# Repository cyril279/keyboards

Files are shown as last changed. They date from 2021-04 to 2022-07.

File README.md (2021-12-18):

# One42 | low-profile 42-key Wireless
choc-v2 & v1 switches, MX-spaced, integrated/onboard nrf52840 controller  
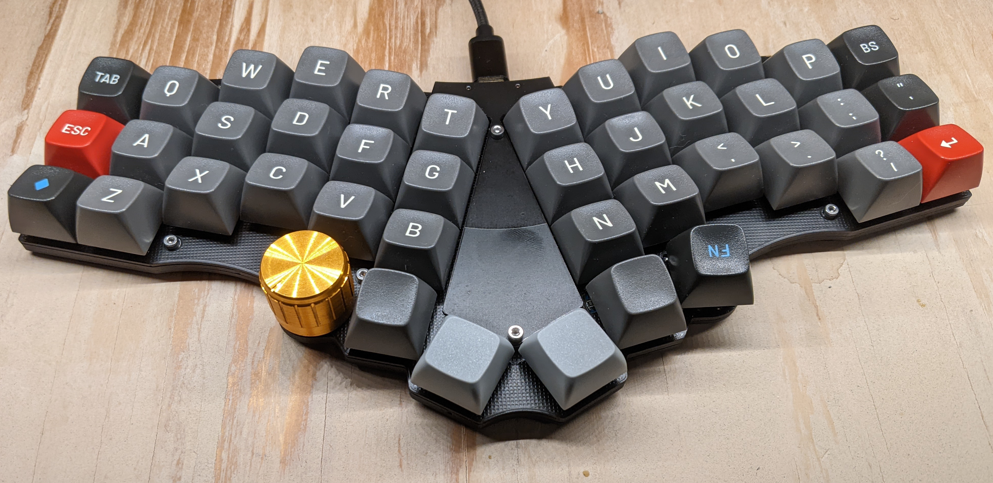
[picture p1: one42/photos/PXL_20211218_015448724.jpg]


# rev41l2 / 41-1353 | low-profile Reviung41 variant
choc-v2 & v1 switches, MX-spaced  
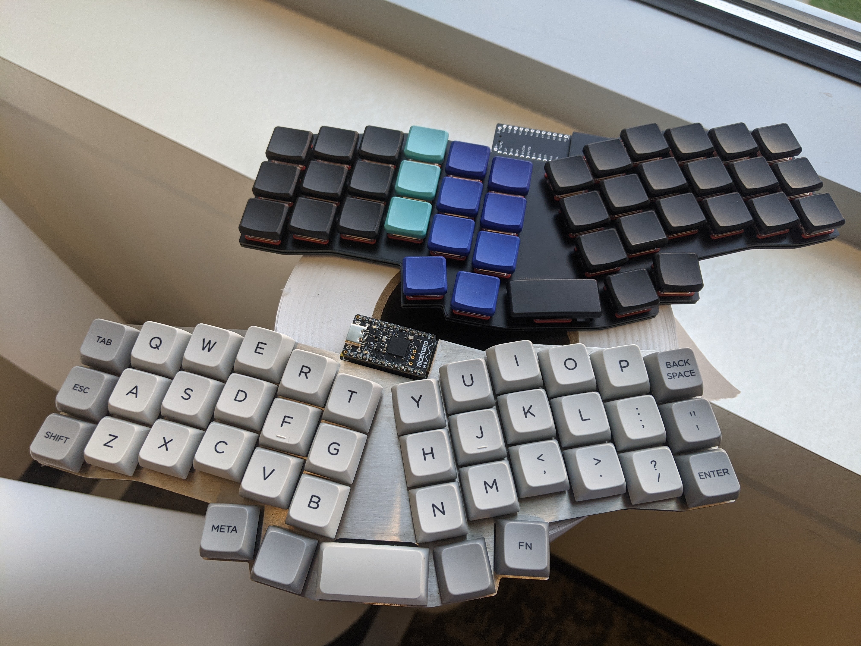
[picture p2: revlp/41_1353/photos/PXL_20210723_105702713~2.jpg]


# rev41lp / 41-1350 | low-profile Reviung41 variant
choc-v1 switches, choc-spaced, hotswap, single-color backlit  
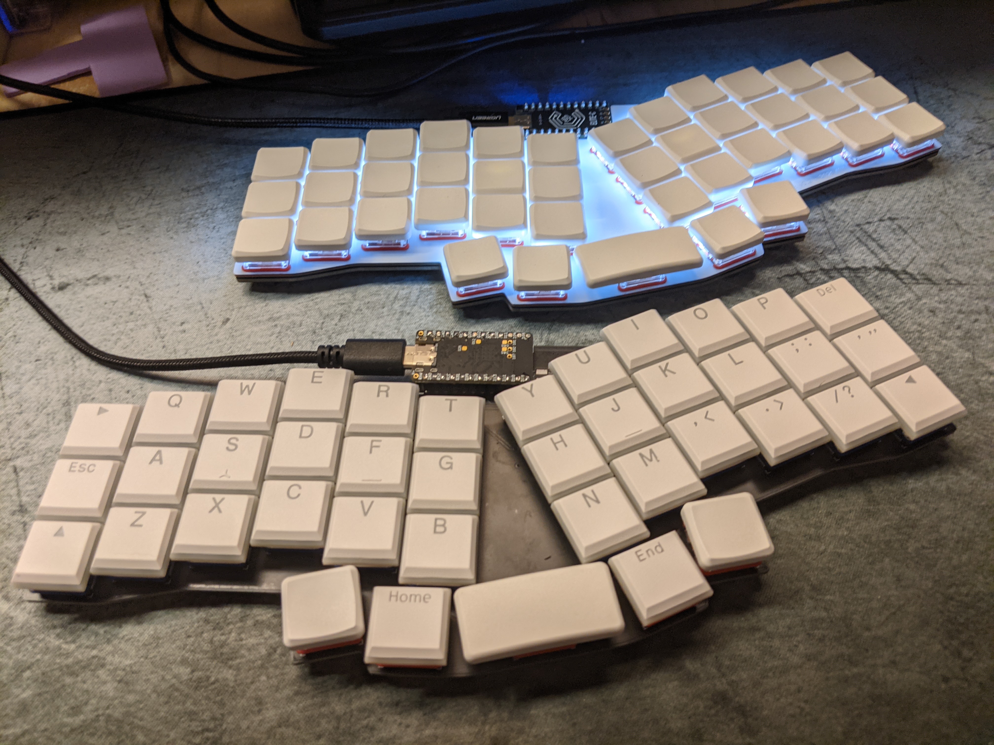
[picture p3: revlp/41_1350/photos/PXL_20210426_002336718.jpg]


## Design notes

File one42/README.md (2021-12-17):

# One42 | 42-key Wireless
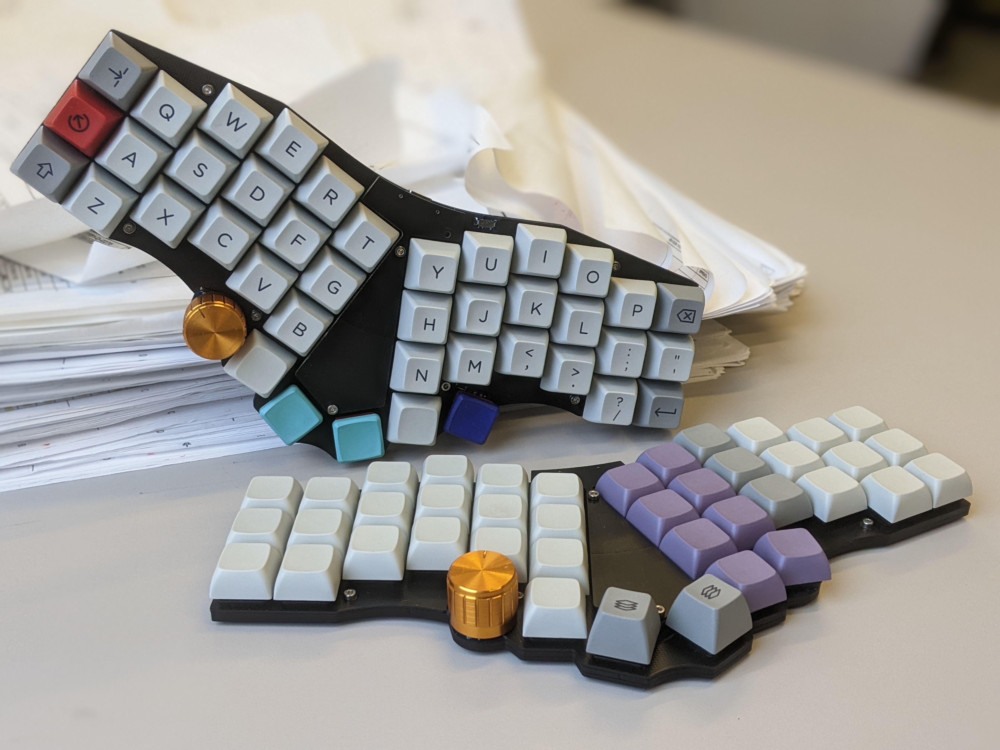
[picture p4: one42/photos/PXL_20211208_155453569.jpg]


- v2 (& v1) choc switches (soldered)
- Integrated/onboard wireless controller (holyiot 18010; hello ZMK!)
- 18.8mm sq.spacing (most keycap dimensions are actually 18.0-18.3mm)
- 30 degree angled halves
- Rotary encoders (2x optional) at outer-thumb positions **
- 100% Hand-solderable
- Minimally cased by Integrated switchplate, skid-plate, & component-cover

## Firmware
[zmk-config](https://github.com/cyril279/zmk-config-one42) << fork, adjust the keymap, and let github build your firmware.  
There are links to the bootloader (if needed), as well as flashing instructions at the link-above.  
For more info on ZMK itself, [* start here *](https://zmk.dev/docs)  

## Encoder fitment
The placement of these encoders allows the use of 21mm diameter knobs.  
  At this diameter, some of the knobs are able to fit down over the body of the encoder for a lower-profiled encoder.  
  Shown below is a 12mm tall encoder adorned with a 21mm diameter knob.  
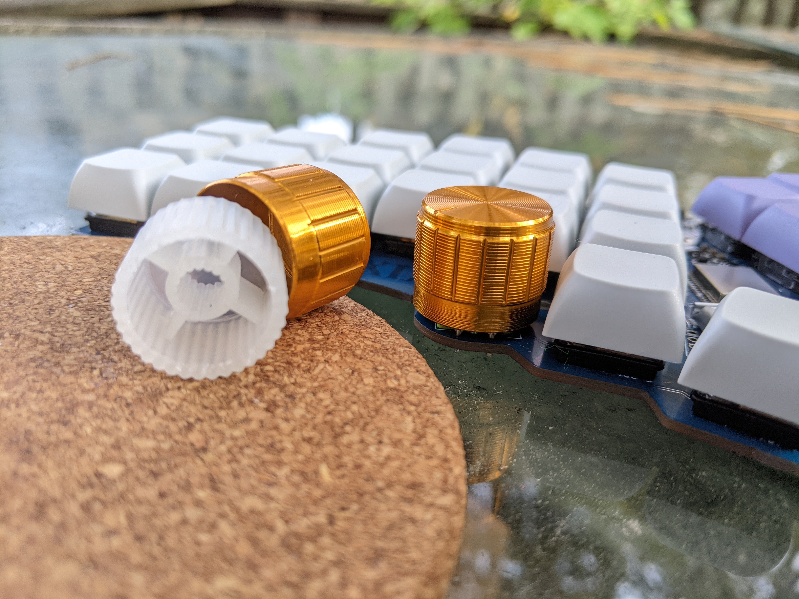
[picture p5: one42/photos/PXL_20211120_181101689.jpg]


## Encasement
A switch-plate, skid-plate, and component cover were designed to make this build nicer to handle and to look at.  
- The switchplate is a 1mm fr4 plate which helps to align the switches, as well as increase curb-appeal. By design, this gets soldered to the pcb via the plated mount-holes.  
- The skidplate is a 1.6mm fr4 plate designed to be fastened to the bottom of the pcb, creating a surface that is much more friendly to handle and have in a bag or backpack, while minimally increasing the height of the overall build.  
- The component-cover is another fr4 plate that covers the topside components.  

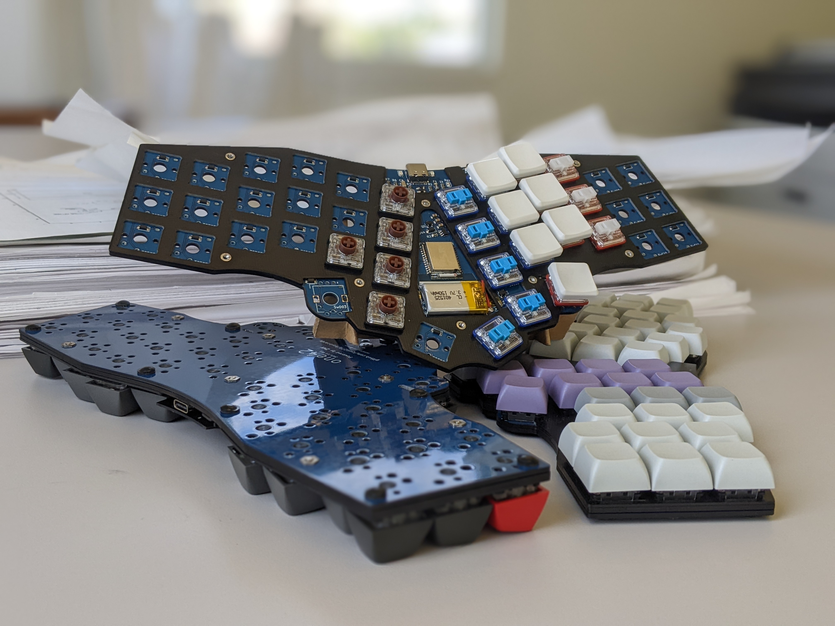
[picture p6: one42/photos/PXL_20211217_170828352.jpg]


## Lessons-learned v0.1 / plans & thoughts for v0.2
1) The pg-1353 switches do not self-align well without a switch-plate.  
  I had hoped (assumed) that the third-leg of the 1353's would do a sufficient job of positioning the switches.  
  My previous designs all involved switch-plates (for aesthetic reasons) so I was unaware that this would be an issue.    
  Switch-plate will be... less optional.  
2) The oval holes for the encoder remove the alignment features for the pg-1350 (choc-v1) switches.  
  The switchplate helps, but does not completely remedy this issue.  
3) Skidplate:  
    a) I will experiment with plating the mount-holes, so that the threaded-inserts can be soldered.  
    b) Leave the copper fill out of the antenna region. This does not seem to affect the current boards, but it was an oversight that it is not removed directly below the antenna.  
4) Component cover: This needs a better finish, but copper filling the whole thing is not an option, because it risks wrecking the wireless signal.  

## Thank You.
- [gtips reviung41](https://github.com/gtips/reviung) was the initial inspiration  
- [dezli’s ahokore](https://github.com/dezlidezlidezli/ahokore) was the template for the zmk-config & electrical-schematic  
- The [low-profile keyboard discord](https://discord.gg/eEK5yUh) is wonderfully encouraging and supportive  
- All things open-source!

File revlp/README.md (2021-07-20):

# Rev-lp
Inspired by the [reviung series](https://github.com/gtips/reviung), designed specifically for Kailh choc switches v1 & v2 (pg1350 & pg1353).  

39_1350 | 39-key Reviung, 18x17mm spacing, v1 switches; hotswap, single-color backlit

[41_1350](./41_1350) | 41-key Reviung, 18x17mm spacing, v1 switches; hotswap, single-color backlit
[](./41_1350)

[41_1353](./41_1353) | 41-key Reviung, 19mm square spacing, v2 (& v1) switches; soldered switches, no lighting
[](./41_1353)

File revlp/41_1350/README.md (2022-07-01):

Cover

# Rev-lp
Inspired by the [reviung series](https://github.com/gtips/reviung), designed specifically for Kailh pg1350 (choc) switches.  

[Build Pics](build.md)  

### Firmware
[QMK](https://github.com/qmk/qmk_firmware/tree/master/keyboards/b_sides/rev41lp)  
[ZMK](https://github.com/cyril279/zmk-config-rev41_1350/tree/main/config)

### Geometric differences from the reviung series:  
- 18mm x 17mm choc key-spacing
- Thumb-row spacing changed to accommodate choc keycap availability 
26 degree splay in between right and left key-groups (gtips’ reviung is 20 degrees)

### Functional differences:  
- Pinouts are different (lack of forethought, this may change)
- Removed underglow (because low-profile)
- Added Per-key (single color), under-switch backlighting
- Addition of battery pads and power switch for use with a bluetooth controller

Mechanical & electronic layouts were performed in fusion360 & kicad (respectively).

### V0.2:
- working as of 2021/04/22 

# Bill of Materials:  

## Required:  
- 1N4148 Smd diodes, SOD-123 / SOD-80 / miniMelf package (39/41)  
- Pg1350 kailh sockets (39/41)  
- Pg1350 switches (39/41)  
- 2u choc stabilizer
- Pro micro (or equivalent)  

## Optional:
- Reset switch ([Alps SKSN series](https://tech.alpsalpine.com/prod/e/html/tact/surfacemount/sksn/sksn_list.html))

### Bluetooth controller:  
- Battery  
- Batt power switch ([Alps SSSS811101](https://tech.alpsalpine.com/prod/e/html/switch/slide/ssss8/ssss811101.html))

### Backlighting:  
- 3528 led's (39/41)  
- Resistors (see backlighting notes), 1206 or melf 0204 package, 1/8 watt (39/41)  
- 4.7k resistor, 1206 or melf 0204 package, 1/8 watt (1)  
- N-channel AO3416 MOSFET, SOT-23 package (1)  

Backlighting notes:  
1. The resistor value needed is determined by specific characteristics of the led's chosen, as well as the voltage supplied by the controller. The specific characteristics can differ for various types and colors of led's.  
2. Use an [led calculator](https://ledcalculator.net/) to determine the resistor value (all ⅛ watt):  
Recommendation: Use minimum resistor needed to protect led, then limit brightness via `BACKLIGHT_LIMIT_VAL` to limit the max to a reasonable value (PWM manged, so more power efficient)  
3. VCC voltage is different for nice!nano from pro-micro; pin 24 is raw on pro-micro, but not on elite-c.  
**V+ choice matters!**  

I am a mechanical cad-person, but I am not a circuit or code whiz, which slowed the effort, and attenuated my ambition.  The success of this project is a direct result of those who took the time to document and publicize their journeys (& kicad projects/libraries), and a supportive low-profile discord community.

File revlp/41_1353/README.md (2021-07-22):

# Reviung41-lp2
Inspired by the [reviung series](https://github.com/gtips/reviung), designed specifically for Kailh pg1353 (choc-v2) switches.  
(Compatible with choc-v1 switches for those that prefer an mx-spaced reviung41)

Cover

This is as low as MX gets.  
Cover

**Firmware:** The pinout is the same as the original reviung41, so the existing Reviung41 firmware ([QMK](https://github.com/qmk/qmk_firmware/tree/master/keyboards/reviung41) or [ZMK](https://zmk.dev/docs/hardware#keyboard-shields)) works for this device.  

**[[ Build Guide ]](build.md)** (work-in-progress)  

**[[ Stabilizer Installation ]](build.md#stabilizer-installation)**  
I have not yet provided guidance on how to mod the bar from its stock-state to work with choc-v2 switches.  
The offset/bent portion of the bar needs to be nearly flat.  

# Bill of Materials:  

## Required:  
- 1N4148 Smd diodes, SOD-123 / SOD-80 / miniMelf package (41)  
- Pg1350 switches (41)  
- 2u costar stabilizer
- Pro micro (or equivalent)  

### Bluetooth controller:  
- Battery  
- Batt power switch ([Alps SSSS811101](https://tech.alpsalpine.com/prod/e/html/switch/slide/ssss8/ssss811101.html))

Initial version notes:

Design:
- Diodes can be mounted under switches, or onto back of PCB
- Switchplate can be soldered to PCB or clipped to switches (depending on desired keycap clearance)
- Use of the switchplate prevents opening of switches while soldered

Notes for future iterations:
- pcb: arrows for stabilizer orientation?
- switch cutout dimension (differs per application):
  - 13.95mm square for v2's that are expected to clip into the plate.
  - 13.8mm square for integrated-plate usage, as well as choc v1 usage. <- More likely scenario
- 2u cutout: Make 1mm wider
- PCB-connection points should be through-hole. (eliminate possibility of lifting the pad | stronger connection of pcb-to-switchplate)
- Thickness (differs per application)
  - 1.6mm when v2-switch clip-in (this option has poor cap compatibility, but looks stellar when applicable)
  - 1.2mm when solder-to-PCB (provides maximum cap compatibility. 1.6mm works, but is awfully close)
- Experiment with 18.5mm spacing.

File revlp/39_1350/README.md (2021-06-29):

!! stay tuned for pics and guide !!

# Bill of Materials:  

## Required:  
- 1N4148 Smd diodes, 1206 package (39)  
- Pg1350 kailh sockets (39)  
- Pg1350 switches (39)  
- pro micro (or equivalent)  

## Optional:
- reset switch ([Alps SKSN series](https://tech.alpsalpine.com/prod/e/html/tact/surfacemount/sksn/sksn_list.html))

### Bluetooth controller:  
- battery  
- batt power switch ([Alps SSSS811101](https://tech.alpsalpine.com/prod/e/html/switch/slide/ssss8/ssss811101.html))

### Backlighting:  
- 3528 led's (39)  
- Resistors (see backlighting notes), 1206 package, 1/8 watt (39)  
- 4.7k resistor, 1206 package, 1/8 watt (1)  
- N-channel AO3416 MOSFET, SOT-23 package (1)  

Backlighting notes:  
1. The resistor value needed is determined by specific characteristics of the led's chosen, as well as the voltage supplied by the controller. The specific characteristics can differ for various types and colors of led's.  
2. Use an [led calculator](https://ledcalculator.net/) to determine the resistor value (all ⅛ watt):  
Recommendation: Use minimum resistor needed to protect led, then limit brightness via `BACKLIGHT_LIMIT_VAL` to limit the max to a reasonable value (PWM manged, so more power efficient)  
3. VCC voltage is different for nice!nano from pro-micro; pin 24 is raw on pro-micro, but not on elite-c. **V+ choice matters!**

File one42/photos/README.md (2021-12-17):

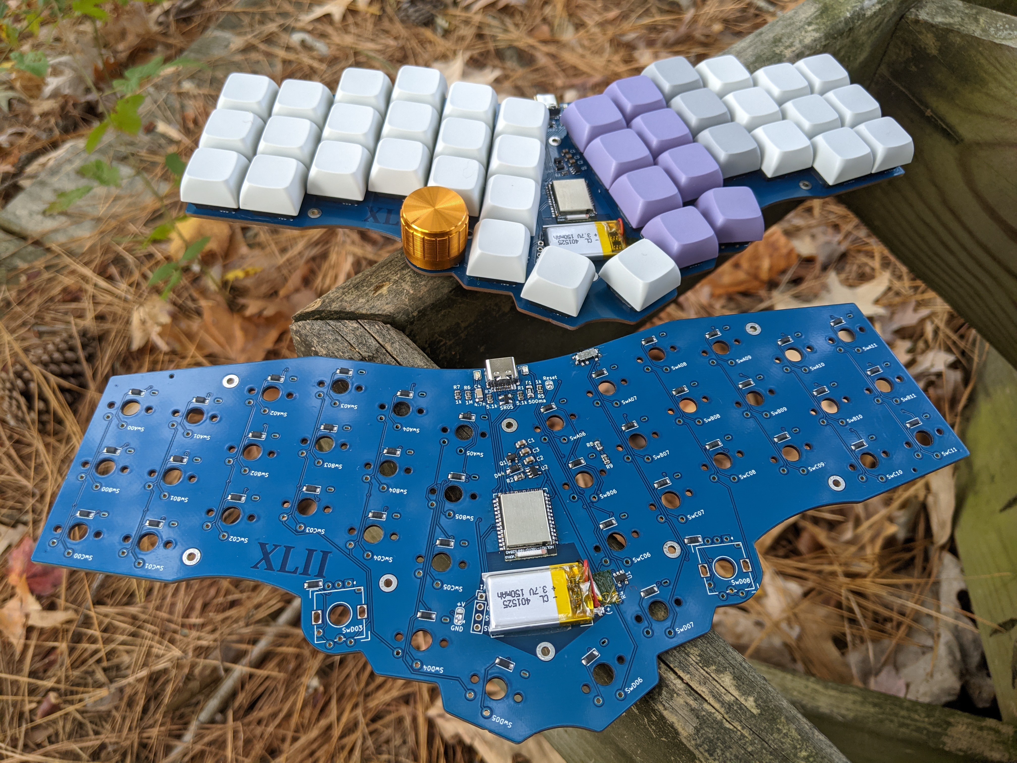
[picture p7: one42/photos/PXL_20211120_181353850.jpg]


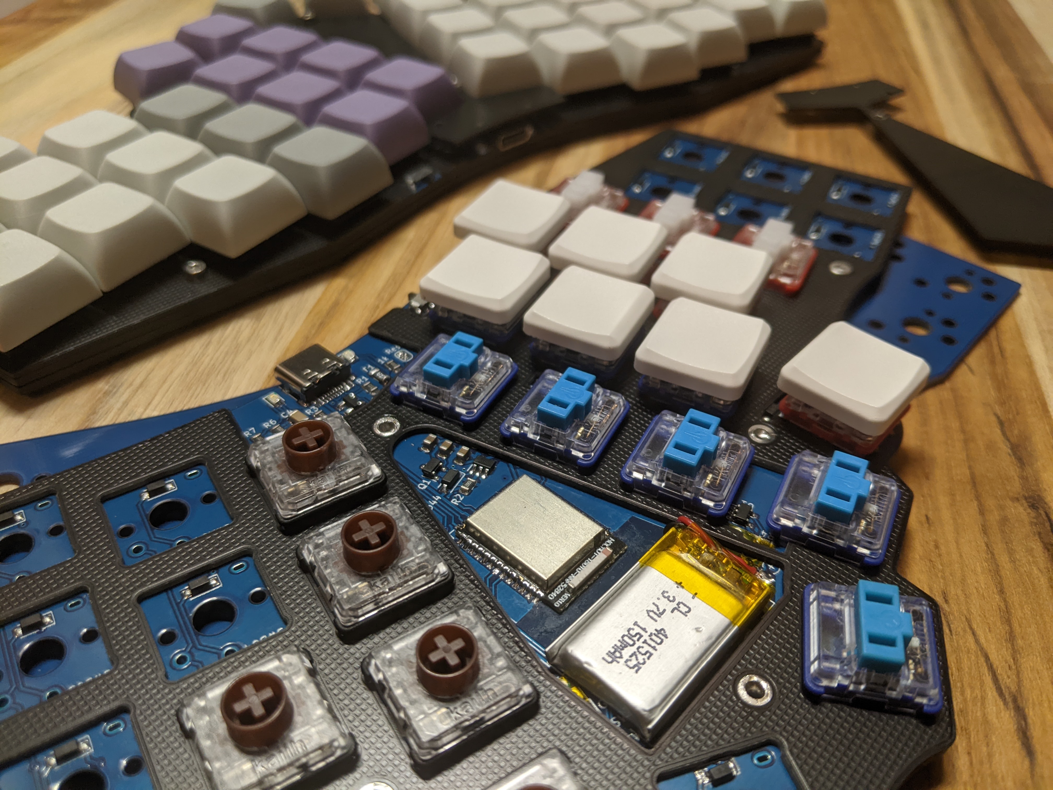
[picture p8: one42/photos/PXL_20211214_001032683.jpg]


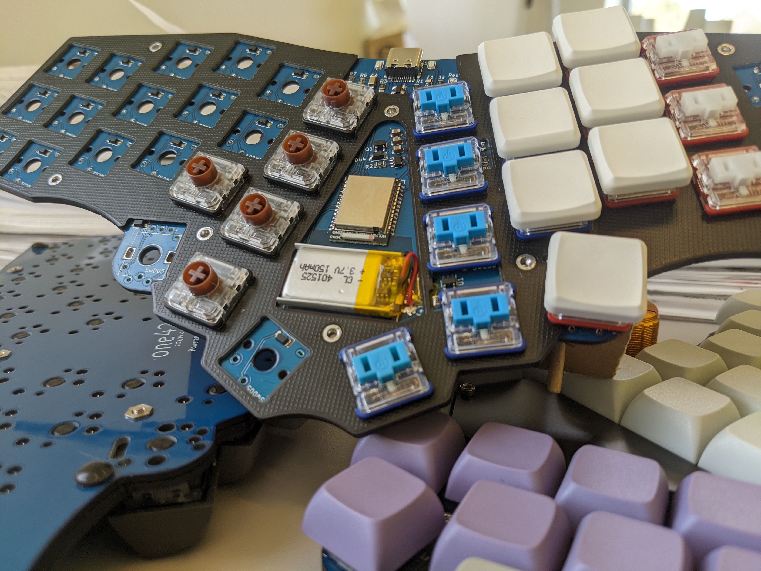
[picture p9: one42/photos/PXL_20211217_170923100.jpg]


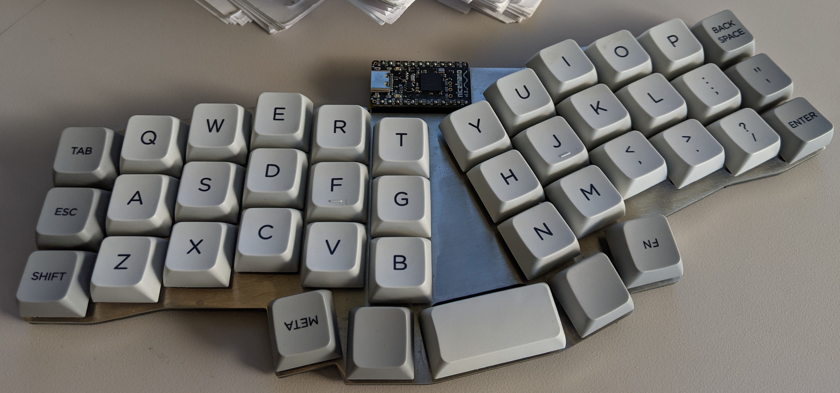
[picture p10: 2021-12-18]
revlp/41_1353/photos/PXL_20210806_121746867_b.jpg

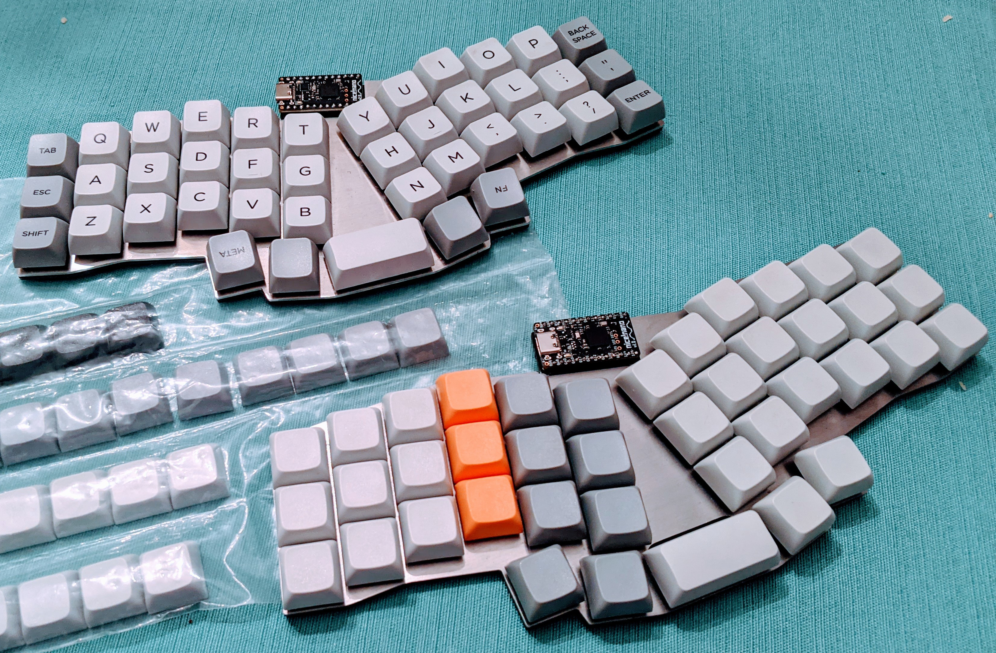
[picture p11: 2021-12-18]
revlp/41_1353/photos/PXL_20210904_000339602~2.jpg

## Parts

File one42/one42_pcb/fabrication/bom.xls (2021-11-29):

Comment | Designator | Footprint | JLCPCB Part #
10k | R4,R2 | 0805 | C17414
4.7uF | C1 | 0805 | C1779
AO3401A | Q1 | SOT-23-3L | C15127
5.1k | R3,R1 | 0805 | C27834
D_Small | D1,D2,D3,D4,D5,D6,D7,D8,D9,D10,D11,D12,D13,D14,D15,D16,D17,D18,D19,D20,D21,D22,D23,D24,D25,D26,D27,D28,D29,D30,D31,D32,D33,D34,D35,D36,D37,D38,D39,D40,D41,D42 | SOD-123 | C81598
2M | R9 | 0805 | C26112
1k | R7,R5 | 0805 | C17513
1uF | C2,C3 | 0805 | C28323
TP4054 | U1 | SOT-23-5 | C32574
1M | R6 | 0805 | C17514

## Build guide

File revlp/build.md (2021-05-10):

build00

Core functionality only requires diodes, hotswap sockets, and a pro-micro compatible controller.  
build02  

Controller must be soldered on face-down.  
I highly recommend socketing the controller.  
build03  

The black strips are .063", adhesive-backed neoprene foam. They provide support while inserting switches, and slightly damp the acoustics of the assembly.  
build04  
The switchplate is not necessary, but I like the added functionality of the 2u stabilizer, as well as the added support provided to the switches.  
build05  

Backlighting:  
Solder mosfet, pull-down resistor (4.7kohm), and led resistors as shown.  
You must choose whether you want for the +V power source to come from the VCC pin, or the RAW (24th) pin of the controller.  
build06  
Align triangle corner of the led with the white corner of the pad.  
build07  

Bluetooth controller (such as nice!nano):  
There are pads on the PCB so that the battery power can be run across an external power switch (also built into the pcb)  
build08

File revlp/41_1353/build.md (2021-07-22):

## Core functionality
1) Flash & test controller
2) Solder diodes (can be soldered to the top or bottom side of pcb)
3) Solder controller to pcb (& test pcb)  


## Bluetooth controller
Solder the battery and power-switch to the pcb (& test again)  




## Integrated Switchplate Installation:
  

Rubber-band the PCB & switchplate together (alignment is not important here)  

  

Insert a few switches (to align the switchplate), but do not raise the switchplate to clip to the switches.  
Leave the switchplate in direct contact with the pcb, the way the rubber-bands are holding them.  
  

Flip the assembly to rest on the switches.  
  

Apply solder to the joint-holes in-between the switches (this joins the pcb & plate together)  
There are twelve.  
  

Complete.
  

## Stabilizer installation
Install guides into PCB with the bar-clip toward the back  


Install inserts into keycap with the offset toward the front  
& install the bar into the inserts with the bend away from the cap-edge  


...with a switch installed...  


Flip the keycap/insert/bar assembly onto the switch  


Align the keycap & inserts to the switch & guides.  
Press the keycap down onto the switch  


Use your bar-insertion tool to press the bar into the clips  



Done.

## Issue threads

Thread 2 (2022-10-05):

Curious Inconsistency On 41_1353 Switch Plate

alexmadeathing, 2022-10-05:
Hi, I was about to order some plates using your files but I noticed a strange inconsistency in the files. One of the 12 solder points that joins the two pcbs together is a drill. Is there a reason I'm not understanding?

My assumption is that all 12 solder points should be the same, either solder pads or drills.

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

cyril279, 2022-10-05:
This was intentional. It has nothing to do with the functionality of the keyboard; instead, I recall that it was related to tricking the JLCPCB system into accepting/interpreting the gerber files correctly.  Otherwise you are correct: ideally those points should all be the same, whether drills or solder pads.

alexmadeathing, 2022-10-05:
Ahh fair enough. And I guess it's better to have just one reasonably hidden via than changing them all to vias and them being more visible.

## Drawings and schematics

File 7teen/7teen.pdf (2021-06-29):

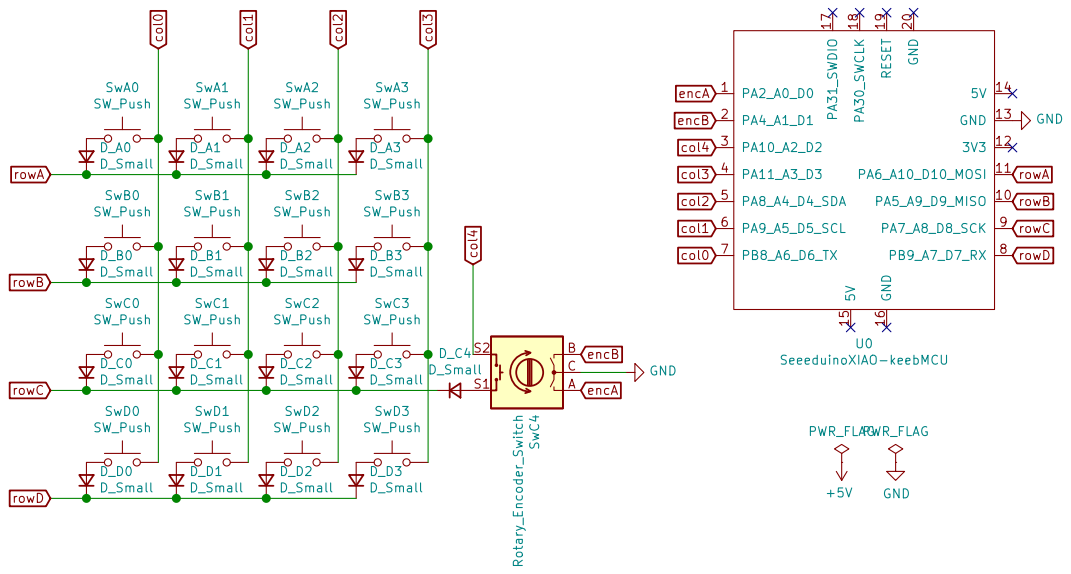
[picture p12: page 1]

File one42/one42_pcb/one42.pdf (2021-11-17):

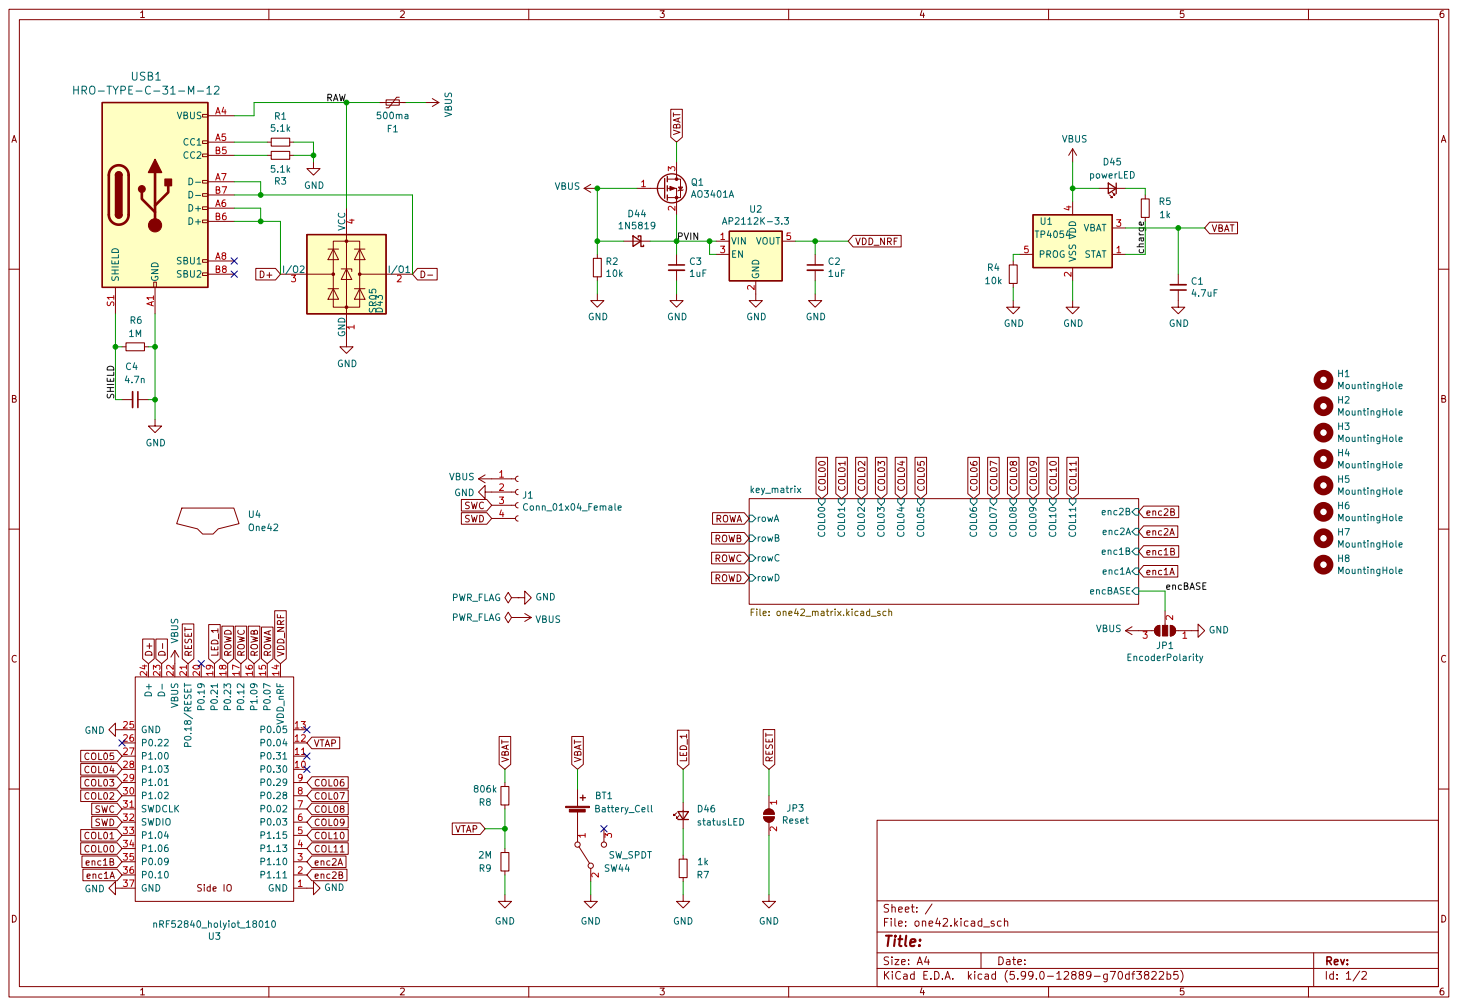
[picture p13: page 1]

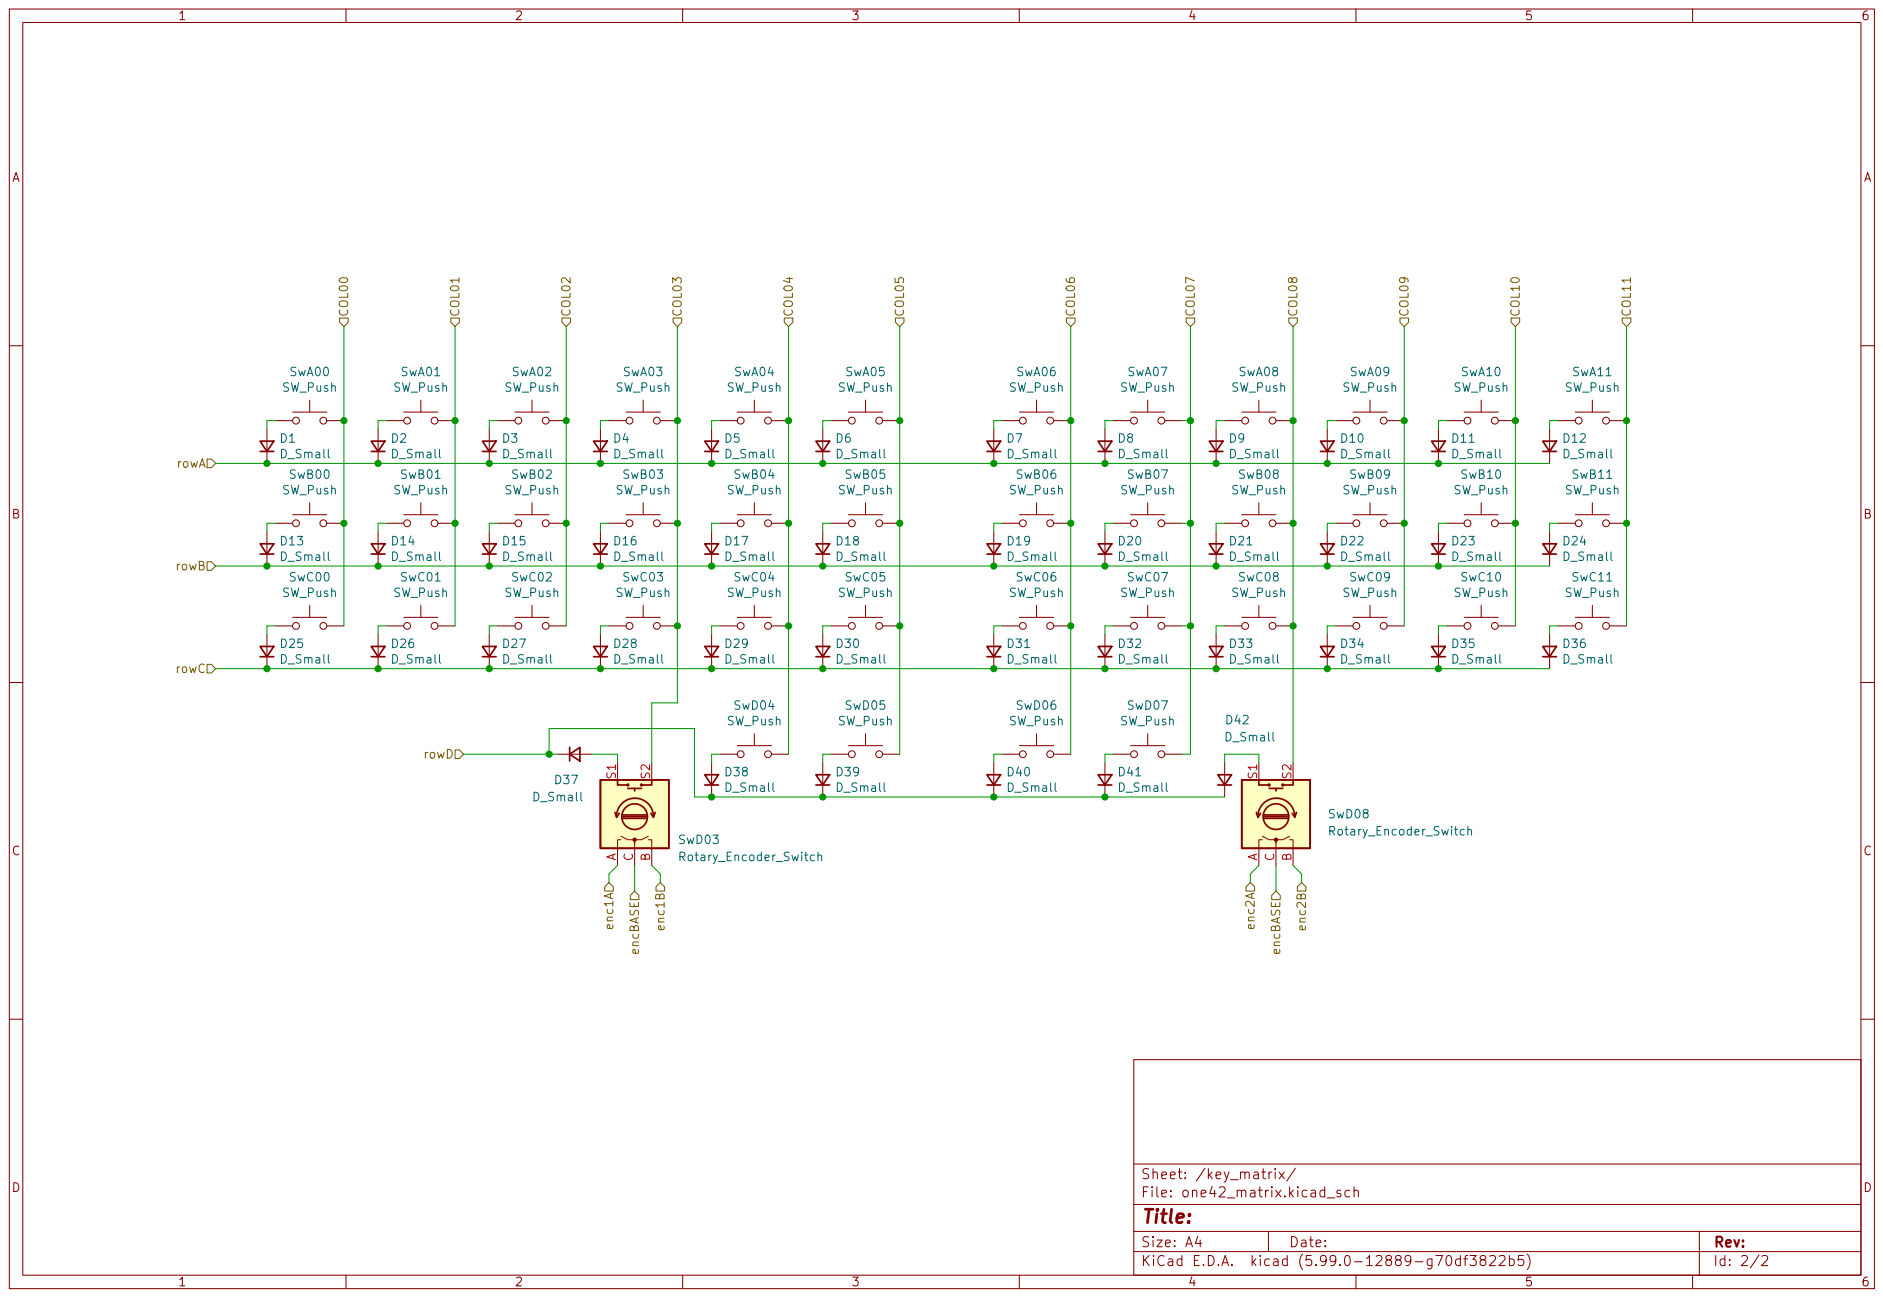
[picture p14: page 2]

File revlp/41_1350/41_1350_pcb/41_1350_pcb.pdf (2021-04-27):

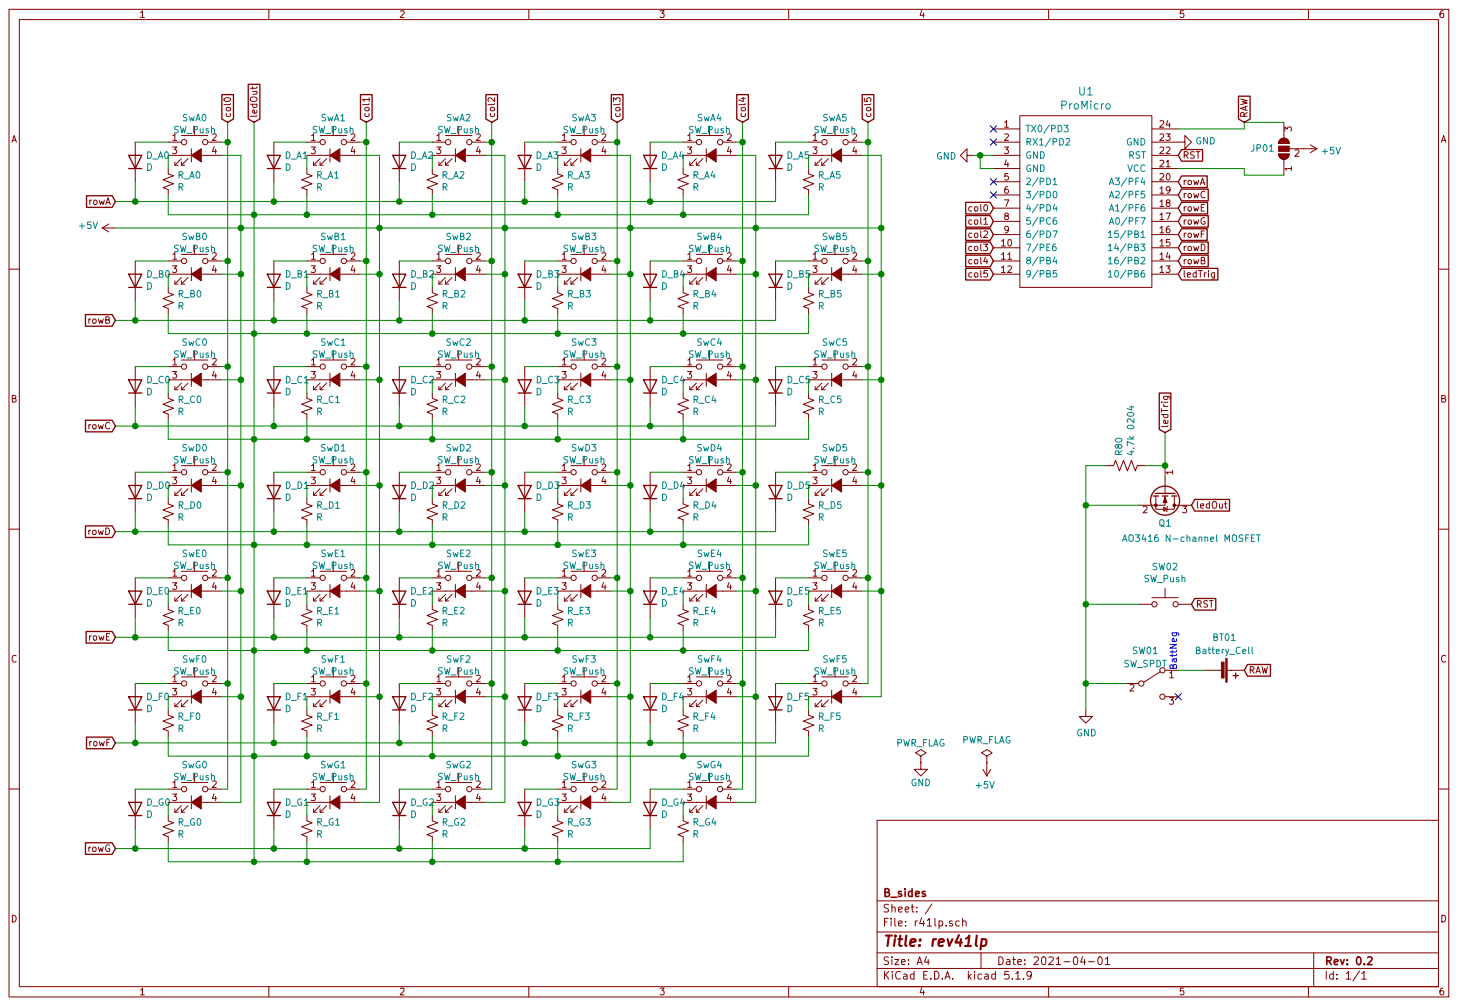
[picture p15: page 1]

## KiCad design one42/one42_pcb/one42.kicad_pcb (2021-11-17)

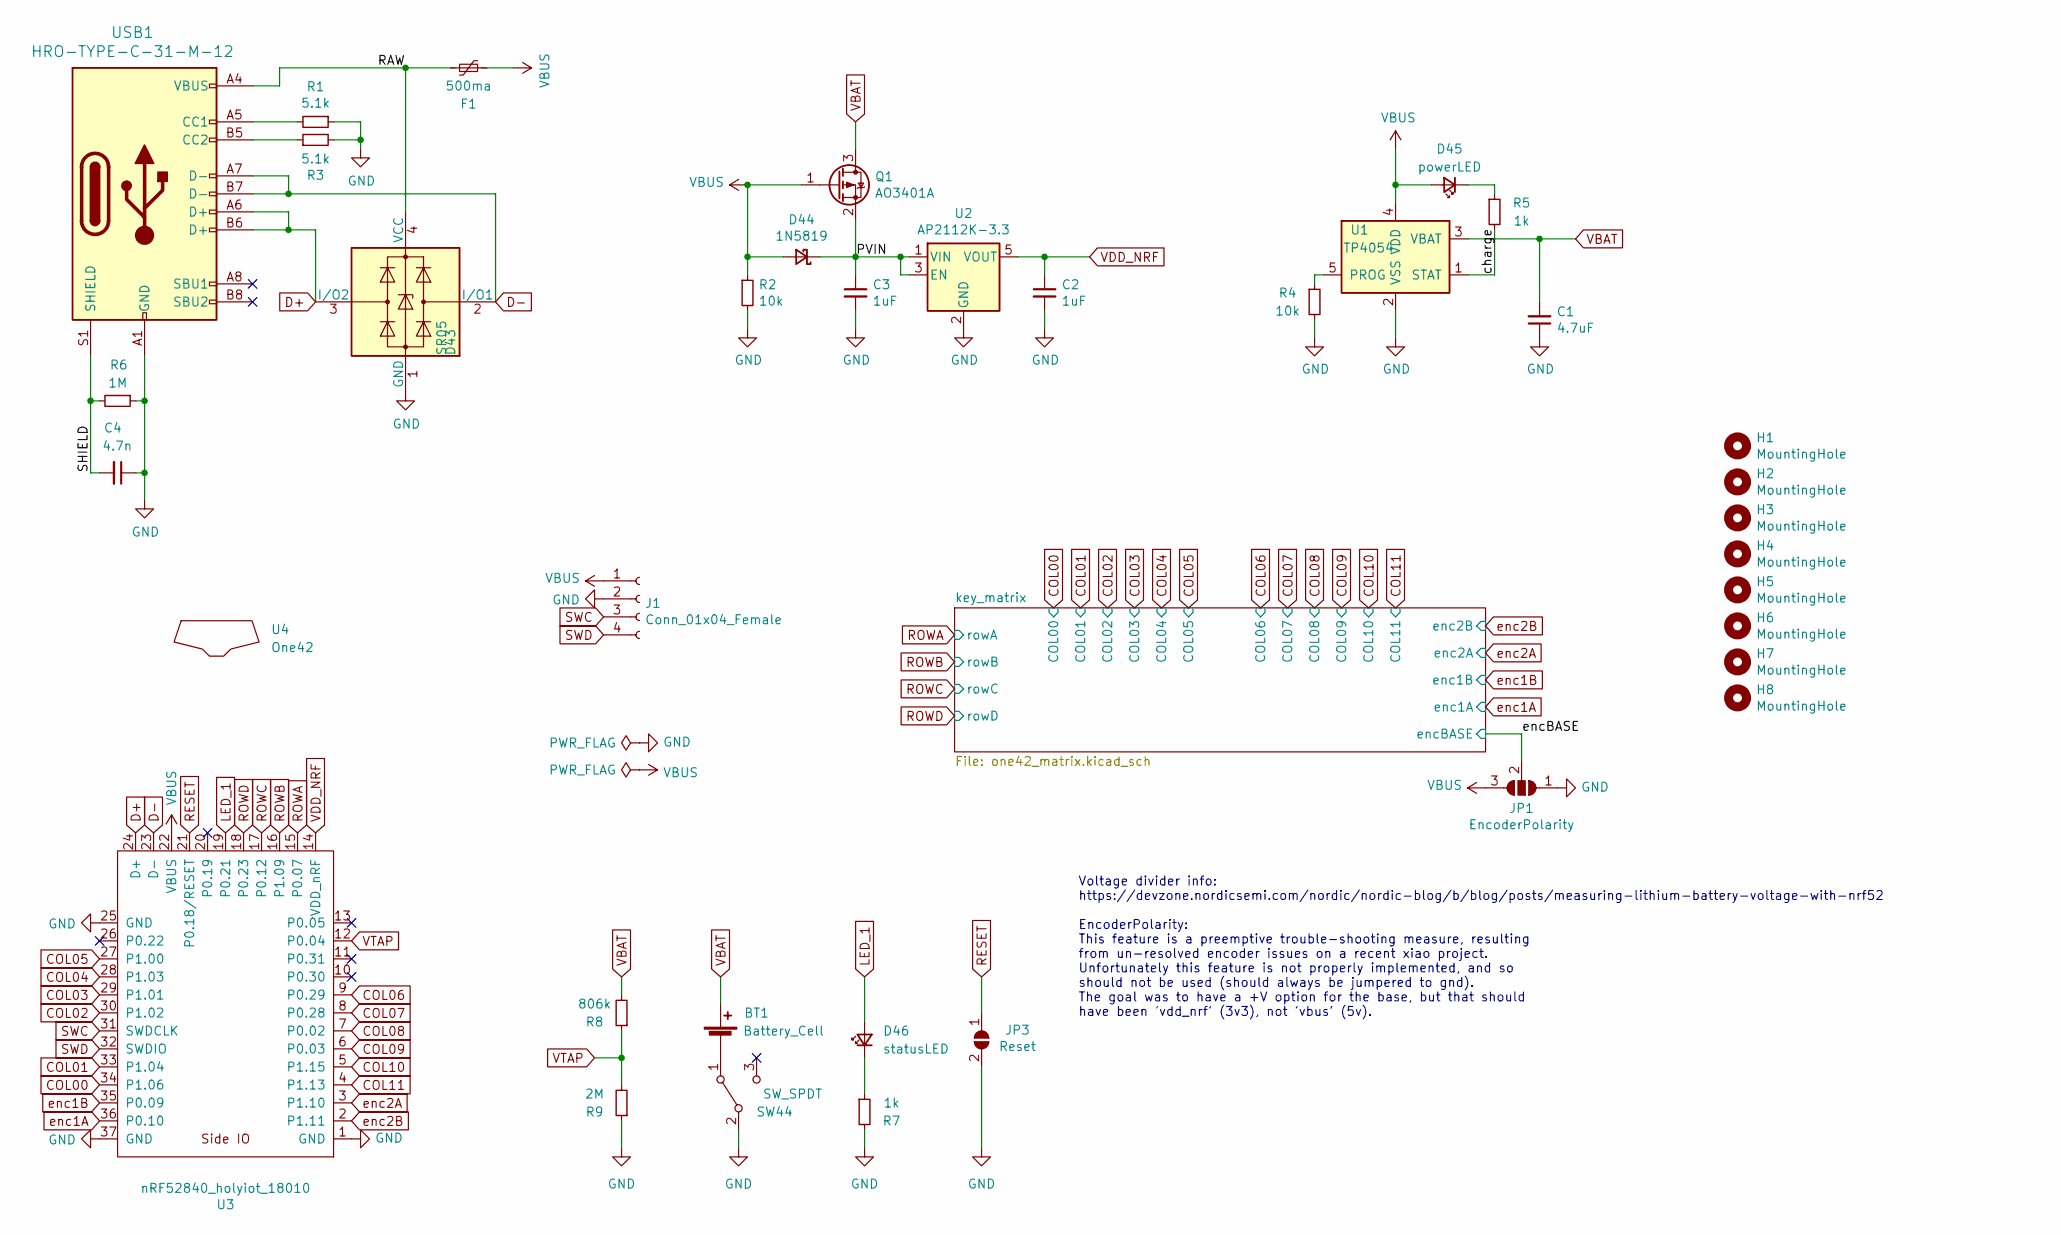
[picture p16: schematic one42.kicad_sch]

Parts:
BT1: Battery_Cell; cell_pads
C1: 4.7uF; C_0805_2012Metric; JLC 0805
C2, C3: 1uF; C_0805_2012Metric; JLC 0805
C4: 4.7n; C_1206_3216Metric
D43: SR05; SOT-143
D44: 1N5819; D_SOD-123
D45: powerLED; D_0805_2012Metric
D46: statusLED; D_0805_2012Metric
F1: 500ma; Fuse_1206_3216Metric
H1, H2, H3, H4, H5, H6, H7, H8: MountingHole; MountingHole_2.2mm_M2_Pad
J1: Conn_01x04_Female; PinHeader_1x04_P2.54mm_Vertical
JP1: EncoderPolarity; SolderJumper-3_P1.3mm_Open_RoundedPad1.0x1.5mm
JP3: Reset; SolderJumper-2_P1.3mm_Open_RoundedPad1.0x1.5mm
Q1: AO3401A; SOT-23; JLC SOT-23-3L
R1, R3: 5.1k; R_0805_2012Metric; JLC 0805
R2, R4: 10k; R_0805_2012Metric; JLC 0805
R5, R7: 1k; R_0805_2012Metric; JLC 0805
R6: 1M; R_0805_2012Metric; JLC 0805
R8: 806k; R_0805_2012Metric
R9: 2M; R_0805_2012Metric; JLC 0805
SW44: SW_SPDT; switch_SSSS811101
U1: TP4054; SOT-23-5; JLC SOT-23-5
U2: AP2112K-3.3; SOT-23-5
U3: nRF52840_holyiot_18010; nRF52840_holyiot_18010_HS_simple
U4: One42; one42
USB1: HRO-TYPE-C-31-M-12; USB_C_Receptacle_HRO_TYPE-C-31-M-12_handsolder

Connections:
/PVIN: C3.1, D44.1 (K), Q1.2 (S), U2.1 (VIN), U2.3 (EN)
/RAW: D43.4 (VCC), F1.2, USB1.A4 (VBUS), USB1.A9 (VBUS), USB1.B4 (VBUS), USB1.B9 (VBUS)
/SHIELD: C4.2, R6.2, USB1.S1 (SHIELD)
/charge: R5.2, U1.1 (STAT)
/encBASE: JP1.2 (C); also elsewhere on the board
COL00: U3.34 (P1.06); also elsewhere on the board
COL01: U3.33 (P1.04); also elsewhere on the board
COL02: U3.30 (P1.02); also elsewhere on the board
COL03: U3.29 (P1.01); also elsewhere on the board
COL04: U3.28 (P1.03); also elsewhere on the board
COL05: U3.27 (P1.00); also elsewhere on the board
COL08: U3.7 (P0.02); also elsewhere on the board
COL09: U3.6 (P0.03); also elsewhere on the board
COL10: U3.5 (P1.15); also elsewhere on the board
COL11: U3.4 (P1.13); also elsewhere on the board
D+: D43.3 (I/O2), U3.24 (D+), USB1.A6 (D+), USB1.B6 (D+)
D-: D43.2 (I/O1), U3.23 (D-), USB1.A7 (D-), USB1.B7 (D-)
GND: C1.1, C2.2, C3.2, C4.1, D43.1 (GND), J1.2, JP1.1 (A), JP3.2 (B), R1.1, R2.2, R3.2, R4.2, R6.1, R7.2, R9.1, SW44.2 (B), U1.2 (VSS), U2.2 (GND), U3.1 (GND), U3.25 (GND), U3.37 (GND), USB1.A1 (GND), USB1.A12 (GND), USB1.B1 (GND), USB1.B12 (GND)
LED_1: D46.2 (A), U3.19 (P0.21)
unnamed: BT1.2 (-), SW44.1 (A)
unnamed: D45.1 (K), R5.1
unnamed: D46.1 (K), R7.1
unnamed: R1.2, USB1.A5 (CC1)
unnamed: R3.1, USB1.B5 (CC2)
unnamed: R4.1, U1.5 (PROG)
RESET: JP3.1 (A), U3.21 (P0.18/RESET)
ROWA: U3.15 (P0.07); also elsewhere on the board
ROWB: U3.16 (P1.09); also elsewhere on the board
ROWC: U3.17 (P0.12); also elsewhere on the board
ROWD: U3.18 (P0.23); also elsewhere on the board
SWC: J1.3, U3.31 (SWDCLK)
SWD: J1.4, U3.32 (SWDIO)
VBAT: BT1.1 (+), C1.2, Q1.3 (D), R8.2, U1.3 (VBAT)
VBUS: D44.2 (A), D45.2 (A), F1.1, J1.1, JP1.3 (B), Q1.1 (G), R2.1, U1.4 (VDD), U3.22 (VBUS)
VDD_NRF: C2.1, U2.5 (VOUT), U3.14 (VDD_nRF)
VTAP: R8.1, R9.2, U3.12 (P0.04)
enc1A: U3.36 (P0.10); also elsewhere on the board
enc1B: U3.35 (P0.09); also elsewhere on the board
enc2A: U3.3 (P1.10); also elsewhere on the board
enc2B: U3.2 (P1.11); also elsewhere on the board

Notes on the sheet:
Voltage divider info: https://devzone.nordicsemi.com/nordic/nordic-blog/b/blog/posts/measuring-lithium-battery-voltage-with-nrf52 EncoderPolarity: This feature is a preemptive trouble-shooting measure, resulting from un-resolved encoder issues on a recent xiao project. Unfortunately this feature is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

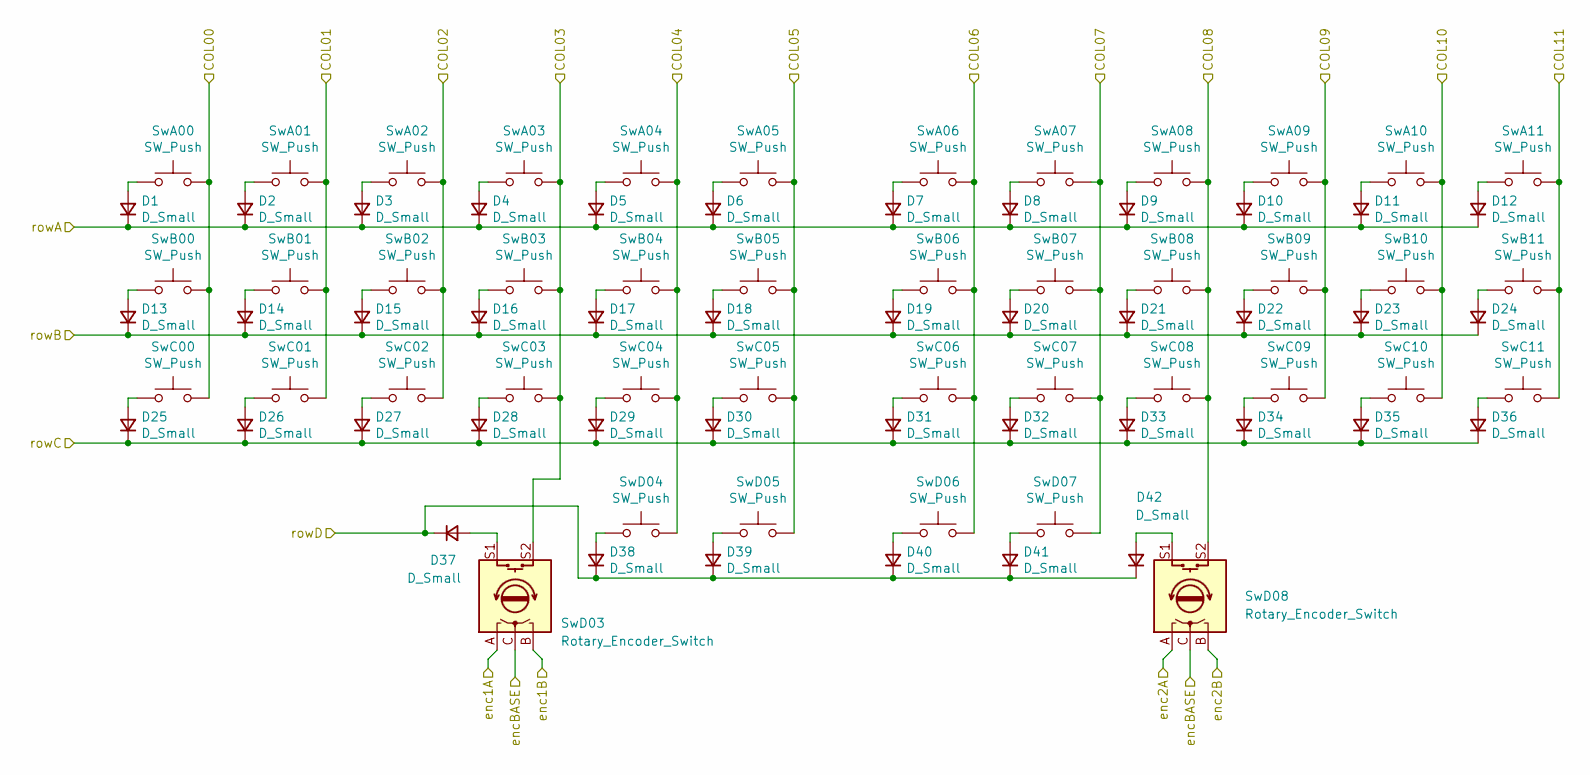
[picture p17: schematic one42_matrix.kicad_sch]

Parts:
D1, D2, D3, D4, D5, D6, D7, D8, D9, D10, D11, D12, D13, D14, D15, D16, D17, D18, D19, D20, D21, D22, D23, D24, D25, D26, D27, D28, D29, D30, D31, D32, D33, D34, D35, D36, D37, D38, D39, D40, D41, D42: D_Small; D_SOD-123; JLC SOD-123
SwA00, SwA01, SwA02, SwA03, SwA04, SwA05, SwA06, SwA07, SwA08, SwA09, SwA10, SwA11: SW_Push; pg1353
SwB00, SwB01, SwB02, SwB03, SwB04, SwB05, SwB06, SwB07, SwB08, SwB09, SwB10, SwB11: SW_Push; pg1353
SwC00, SwC01, SwC02, SwC03, SwC04, SwC05, SwC06, SwC07, SwC08, SwC09, SwC10, SwC11: SW_Push; pg1353
SwD03, SwD08: Rotary_Encoder_Switch; pg1353_ec11rotSw
SwD04, SwD05, SwD06, SwD07: SW_Push; pg1353

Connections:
/encBASE: SwD03.C, SwD08.C; also elsewhere on the board
COL00: SwA00.2, SwB00.2, SwC00.2; also elsewhere on the board
COL01: SwA01.2, SwB01.2, SwC01.2; also elsewhere on the board
COL02: SwA02.2, SwB02.2, SwC02.2; also elsewhere on the board
COL03: SwA03.2, SwB03.2, SwC03.2, SwD03.S2; also elsewhere on the board
COL04: SwA04.2, SwB04.2, SwC04.2, SwD04.2; also elsewhere on the board
COL05: SwA05.2, SwB05.2, SwC05.2, SwD05.2; also elsewhere on the board
COL08: SwA08.2, SwB08.2, SwC08.2, SwD08.S2; also elsewhere on the board
COL09: SwA09.2, SwB09.2, SwC09.2; also elsewhere on the board
COL10: SwA10.2, SwB10.2, SwC10.2; also elsewhere on the board
COL11: SwA11.2, SwB11.2, SwC11.2; also elsewhere on the board
unnamed: D1.2 (A), SwA00.1
unnamed: D2.2 (A), SwA01.1
unnamed: D3.2 (A), SwA02.1
unnamed: D4.2 (A), SwA03.1
unnamed: D5.2 (A), SwA04.1
unnamed: D6.2 (A), SwA05.1
unnamed: D7.2 (A), SwA06.1
unnamed: D8.2 (A), SwA07.1
unnamed: D9.2 (A), SwA08.1
unnamed: D10.2 (A), SwA09.1
unnamed: D11.2 (A), SwA10.1
unnamed: D12.2 (A), SwA11.1
unnamed: D13.2 (A), SwB00.1
unnamed: D14.2 (A), SwB01.1
unnamed: D15.2 (A), SwB02.1
unnamed: D16.2 (A), SwB03.1
unnamed: D17.2 (A), SwB04.1
unnamed: D18.2 (A), SwB05.1
unnamed: D19.2 (A), SwB06.1
unnamed: D20.2 (A), SwB07.1
unnamed: D21.2 (A), SwB08.1
unnamed: D22.2 (A), SwB09.1
unnamed: D23.2 (A), SwB10.1
unnamed: D24.2 (A), SwB11.1
unnamed: D25.2 (A), SwC00.1
unnamed: D26.2 (A), SwC01.1
unnamed: D27.2 (A), SwC02.1
unnamed: D28.2 (A), SwC03.1
unnamed: D29.2 (A), SwC04.1
unnamed: D30.2 (A), SwC05.1
unnamed: D31.2 (A), SwC06.1
unnamed: D32.2 (A), SwC07.1
unnamed: D33.2 (A), SwC08.1
unnamed: D34.2 (A), SwC09.1
unnamed: D35.2 (A), SwC10.1
unnamed: D36.2 (A), SwC11.1
unnamed: D37.2 (A), SwD03.S1
unnamed: D38.2 (A), SwD04.1
unnamed: D39.2 (A), SwD05.1
unnamed: D42.2 (A), SwD08.S1
ROWA: D1.1 (K), D2.1 (K), D3.1 (K), D4.1 (K), D5.1 (K), D6.1 (K), D7.1 (K), D8.1 (K), D9.1 (K), D10.1 (K), D11.1 (K), D12.1 (K); also elsewhere on the board
ROWB: D13.1 (K), D14.1 (K), D15.1 (K), D16.1 (K), D17.1 (K), D18.1 (K), D19.1 (K), D20.1 (K), D21.1 (K), D22.1 (K), D23.1 (K), D24.1 (K); also elsewhere on the board
ROWC: D25.1 (K), D26.1 (K), D27.1 (K), D28.1 (K), D29.1 (K), D30.1 (K), D31.1 (K), D32.1 (K), D33.1 (K), D34.1 (K), D35.1 (K), D36.1 (K); also elsewhere on the board
ROWD: D37.1 (K), D38.1 (K), D39.1 (K), D40.1 (K), D41.1 (K), D42.1 (K); also elsewhere on the board
enc1A: SwD03.A; also elsewhere on the board
enc1B: SwD03.B; also elsewhere on the board
enc2A: SwD08.A; also elsewhere on the board
enc2B: SwD08.B; also elsewhere on the board

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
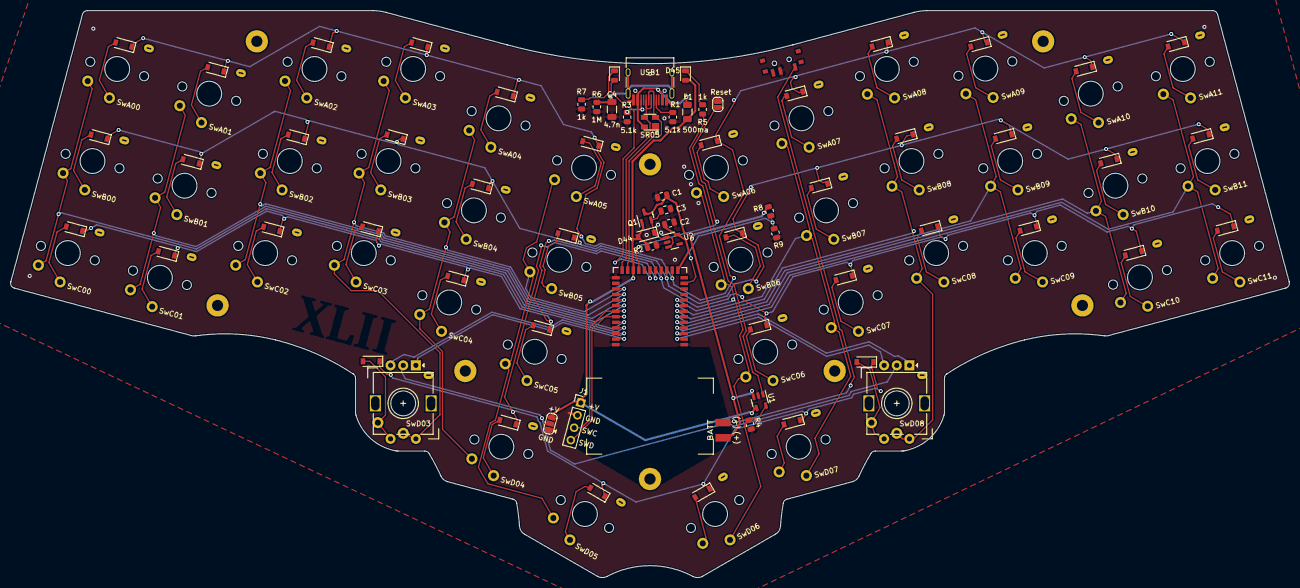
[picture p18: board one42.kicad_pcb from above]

Board: 2 copper layers, 252.3 x 111.8 mm, 121 parts (0 on the bottom side), 84 nets.

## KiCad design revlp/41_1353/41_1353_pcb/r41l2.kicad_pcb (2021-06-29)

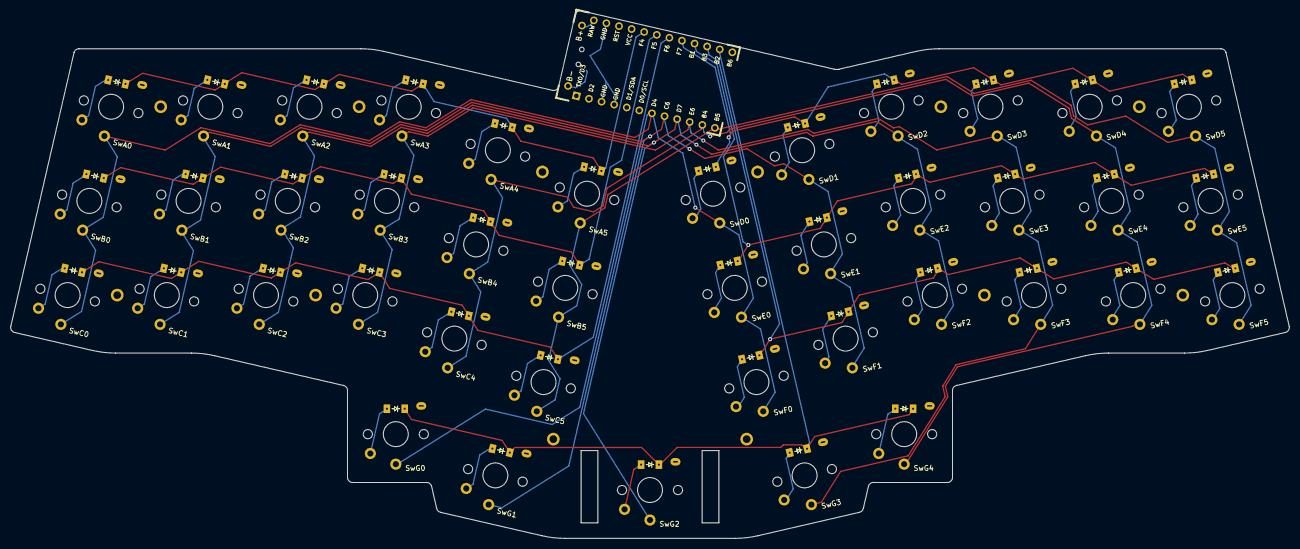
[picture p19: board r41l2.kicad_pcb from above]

Board: 2 copper layers, 251.3 x 103.7 mm, 84 parts (1 on the bottom side), 57 nets.

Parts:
D_A0, D_A1, D_A2, D_A3, D_A4, D_A5: D; D_MiniMELF_bsides
D_B0, D_B1, D_B2, D_B3, D_B4, D_B5: D; D_MiniMELF_bsides
D_C0, D_C1, D_C2, D_C3, D_C4, D_C5: D; D_MiniMELF_bsides
D_D0, D_D1, D_D2, D_D3, D_D4, D_D5: D; D_MiniMELF_bsides
D_E0, D_E1, D_E2, D_E3, D_E4, D_E5: D; D_MiniMELF_bsides
D_F0, D_F1, D_F2, D_F3, D_F4, D_F5: D; D_MiniMELF_bsides
D_G0, D_G1, D_G2, D_G3, D_G4: D; D_MiniMELF_bsides
SW01: SW_SPDT; switch_SSSS811101
SwA0, SwA1, SwA2, SwA3, SwA4, SwA5: SW_Push; pg1353
SwB0, SwB1, SwB2, SwB3, SwB4, SwB5: SW_Push; pg1353
SwC0, SwC1, SwC2, SwC3, SwC4, SwC5: SW_Push; pg1353
SwD0, SwD1, SwD2, SwD3, SwD4, SwD5: SW_Push; pg1353
SwE0, SwE1, SwE2, SwE3, SwE4, SwE5: SW_Push; pg1353
SwF0, SwF1, SwF2, SwF3, SwF4, SwF5: SW_Push; pg1353
SwG0, SwG1, SwG3, SwG4: SW_Push; pg1353
SwG2: SW_Push; pg1353_2u
U1: ProMicro; ProMicroNiced

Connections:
GND: SW01.2, U1.3, U1.4, U1.23
unnamed: D_A0.2, SwA0.1
unnamed: D_A1.2, SwA1.1
unnamed: D_A2.2, SwA2.1
unnamed: D_A3.2, SwA3.1
unnamed: D_A4.2, SwA4.1
unnamed: D_A5.2, SwA5.1
unnamed: D_B0.2, SwB0.1
unnamed: D_B1.2, SwB1.1
unnamed: D_B2.2, SwB2.1
unnamed: D_B3.2, SwB3.1
unnamed: D_B4.2, SwB4.1
unnamed: D_B5.2, SwB5.1
unnamed: D_C0.2, SwC0.1
unnamed: D_C1.2, SwC1.1
unnamed: D_C2.2, SwC2.1
unnamed: D_C3.2, SwC3.1
unnamed: D_C4.2, SwC4.1
unnamed: D_C5.2, SwC5.1
unnamed: D_D0.2, SwD0.1
unnamed: D_D1.2, SwD1.1
unnamed: D_D2.2, SwD2.1
unnamed: D_D3.2, SwD3.1
unnamed: D_D4.2, SwD4.1
unnamed: D_D5.2, SwD5.1
unnamed: D_E0.2, SwE0.1
unnamed: D_E1.2, SwE1.1
unnamed: D_E2.2, SwE2.1
unnamed: D_E3.2, SwE3.1
unnamed: D_E4.2, SwE4.1
unnamed: D_E5.2, SwE5.1
unnamed: D_F0.2, SwF0.1
unnamed: D_F1.2, SwF1.1
unnamed: D_F2.2, SwF2.1
unnamed: D_F3.2, SwF3.1
unnamed: D_F4.2, SwF4.1
unnamed: D_F5.2, SwF5.1
unnamed: D_G0.2, SwG0.1
unnamed: D_G1.2, SwG1.1
unnamed: D_G2.2, SwG2.1
unnamed: D_G3.2, SwG3.1
unnamed: D_G4.2, SwG4.1
unnamed: SW01.1, U1.0
unnamed: U1.24, U1.25
col0: SwA0.2, SwB0.2, SwC0.2, SwD0.2, SwE0.2, SwF0.2, SwG0.2, U1.7
col1: SwA1.2, SwB1.2, SwC1.2, SwD1.2, SwE1.2, SwF1.2, SwG1.2, U1.8
col2: SwA2.2, SwB2.2, SwC2.2, SwD2.2, SwE2.2, SwF2.2, SwG2.2, U1.9
col3: SwA3.2, SwB3.2, SwC3.2, SwD3.2, SwE3.2, SwF3.2, SwG3.2, U1.10
col4: SwA4.2, SwB4.2, SwC4.2, SwD4.2, SwE4.2, SwF4.2, SwG4.2, U1.11
col5: SwA5.2, SwB5.2, SwC5.2, SwD5.2, SwE5.2, SwF5.2, U1.12
rowA: D_A0.1, D_A1.1, D_A2.1, D_A3.1, D_A4.1, D_A5.1, U1.20
rowB: D_B0.1, D_B1.1, D_B2.1, D_B3.1, D_B4.1, D_B5.1, U1.19
rowC: D_C0.1, D_C1.1, D_C2.1, D_C3.1, D_C4.1, D_C5.1, U1.18
rowD: D_D0.1, D_D1.1, D_D2.1, D_D3.1, D_D4.1, D_D5.1, U1.17
rowE: D_E0.1, D_E1.1, D_E2.1, D_E3.1, D_E4.1, D_E5.1, U1.16
rowF: D_F0.1, D_F1.1, D_F2.1, D_F3.1, D_F4.1, D_F5.1, U1.15
rowG: D_G0.1, D_G1.1, D_G2.1, D_G3.1, D_G4.1, U1.14

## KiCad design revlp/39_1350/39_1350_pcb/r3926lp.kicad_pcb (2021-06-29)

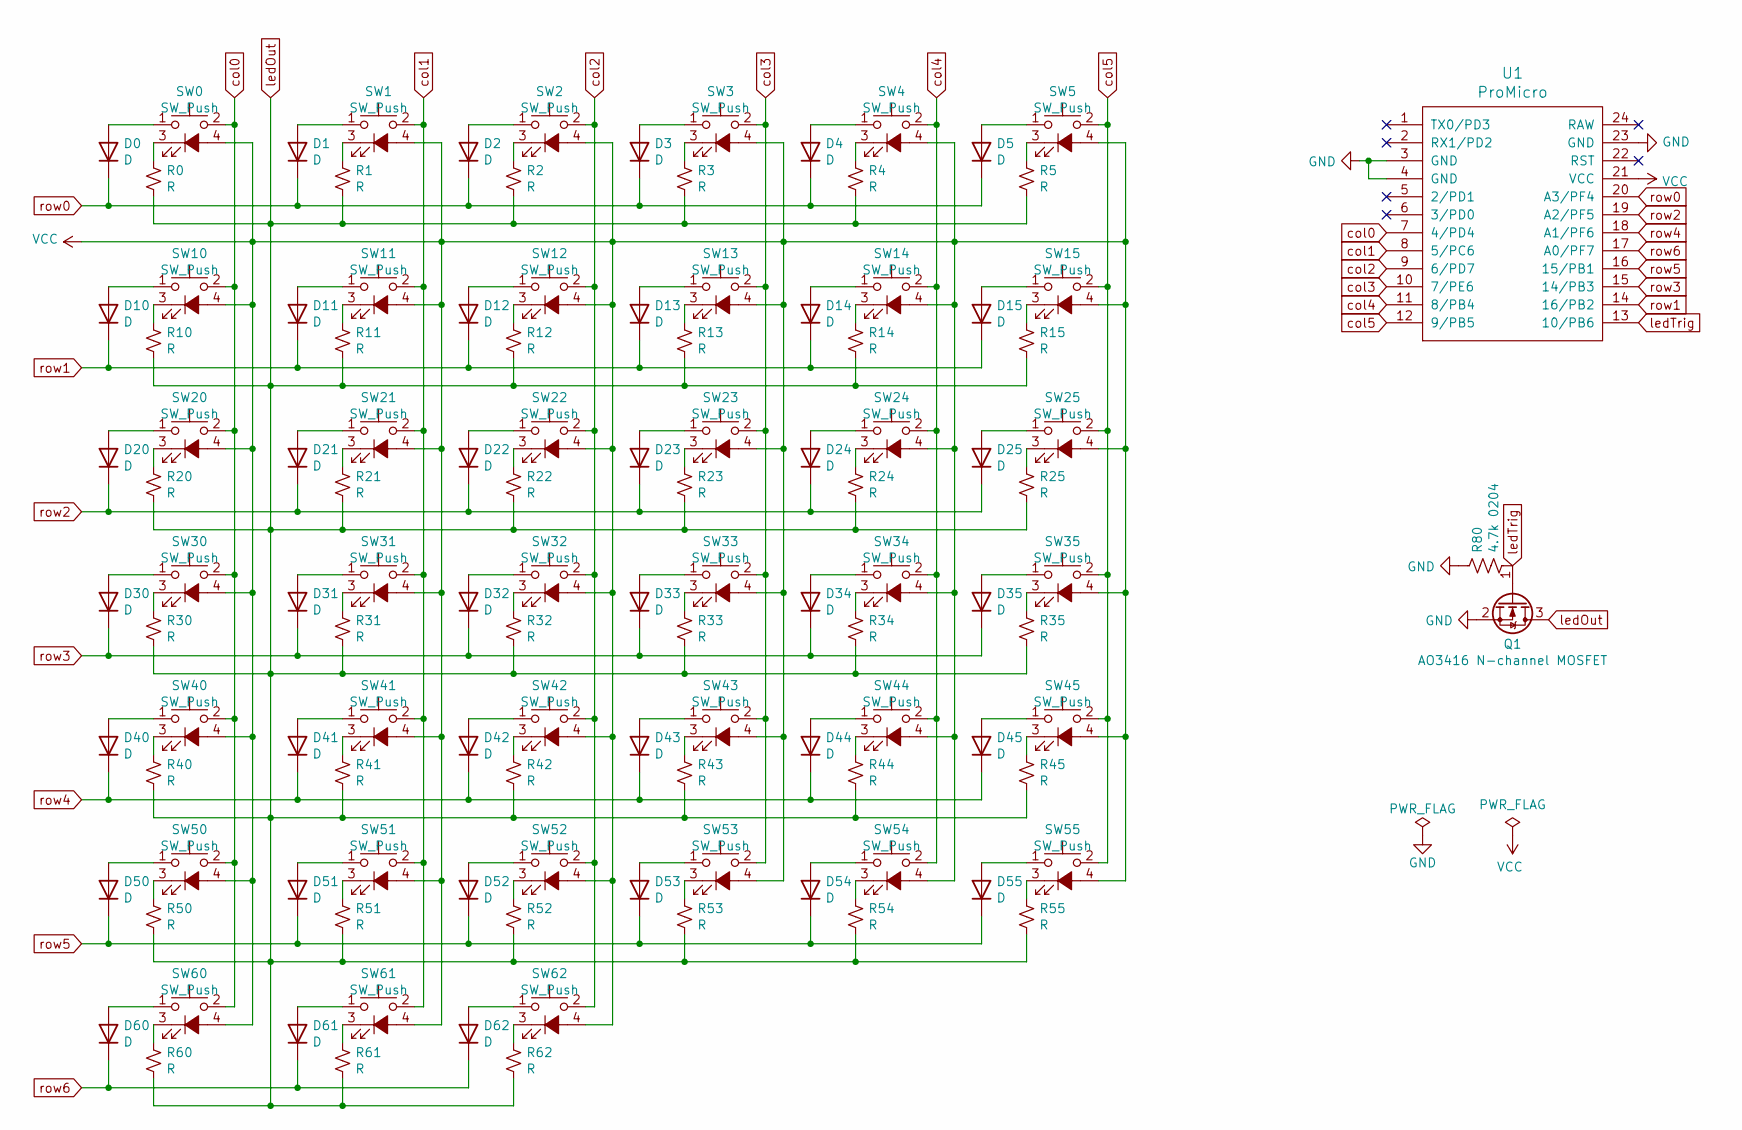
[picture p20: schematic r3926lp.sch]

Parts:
D0, D1, D2, D3, D4, D5, D10, D11, D12, D13, D14, D15, D20, D21, D22, D23, D24, D25, D30, D31, D32, D33, D34, D35, D40, D41, D42, D43, D44, D45, D50, D51, D52, D53, D54, D55, D60, D61, D62: D; D_MiniMELF
Q1: AO3416 N-channel MOSFET; SOT-23
R0, R1, R2, R3, R4, R5, R10, R11, R12, R13, R14, R15, R20, R21, R22, R23, R24, R25, R30, R31, R32, R33, R34, R35, R40, R41, R42, R43, R44, R45, R50, R51, R52, R53, R54, R55, R60, R61, R62: R; R_MiniMELF_MMA-0204
R80: 4.7k 0204; R_MiniMELF_MMA-0204
SW0, SW1, SW2, SW3, SW4, SW5, SW10, SW11, SW12, SW13, SW14, SW15, SW20, SW21, SW22, SW23, SW24, SW25, SW30, SW31, SW32, SW33, SW34, SW35, SW40, SW41, SW42, SW43, SW44, SW45, SW50, SW51, SW52, SW53, SW54, SW55, SW60, SW61, SW62: SW_Push; PG1350_socket_smdLed
U1: ProMicro; ArduinoProMicro

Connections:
GND: Q1.2 (S), R80.2, U1.3 (GND), U1.4 (GND), U1.23 (GND)
unnamed: D0.2 (A), SW0.1
unnamed: D1.2 (A), SW1.1
unnamed: D2.2 (A), SW2.1
unnamed: D3.2 (A), SW3.1
unnamed: D4.2 (A), SW4.1
unnamed: D5.2 (A), SW5.1
unnamed: D10.2 (A), SW10.1
unnamed: D11.2 (A), SW11.1
unnamed: D12.2 (A), SW12.1
unnamed: D13.2 (A), SW13.1
unnamed: D14.2 (A), SW14.1
unnamed: D15.2 (A), SW15.1
unnamed: D20.2 (A), SW20.1
unnamed: D21.2 (A), SW21.1
unnamed: D22.2 (A), SW22.1
unnamed: D23.2 (A), SW23.1
unnamed: D24.2 (A), SW24.1
unnamed: D25.2 (A), SW25.1
unnamed: D30.2 (A), SW30.1
unnamed: D31.2 (A), SW31.1
unnamed: D32.2 (A), SW32.1
unnamed: D33.2 (A), SW33.1
unnamed: D34.2 (A), SW34.1
unnamed: D35.2 (A), SW35.1
unnamed: D40.2 (A), SW40.1
unnamed: D41.2 (A), SW41.1
unnamed: D42.2 (A), SW42.1
unnamed: D43.2 (A), SW43.1
unnamed: D44.2 (A), SW44.1
unnamed: D45.2 (A), SW45.1
unnamed: D50.2 (A), SW50.1
unnamed: D51.2 (A), SW51.1
unnamed: D52.2 (A), SW52.1
unnamed: D53.2 (A), SW53.1
unnamed: D54.2 (A), SW54.1
unnamed: D55.2 (A), SW55.1
unnamed: D60.2 (A), SW60.1
unnamed: D61.2 (A), SW61.1
unnamed: D62.2 (A), SW62.1
unnamed: R0.2, SW0.3 (K)
unnamed: R1.2, SW1.3 (K)
unnamed: R2.2, SW2.3 (K)
unnamed: R3.2, SW3.3 (K)
unnamed: R4.2, SW4.3 (K)
unnamed: R5.2, SW5.3 (K)
unnamed: R10.2, SW10.3 (K)
unnamed: R11.2, SW11.3 (K)
unnamed: R12.2, SW12.3 (K)
unnamed: R13.2, SW13.3 (K)
unnamed: R14.2, SW14.3 (K)
unnamed: R15.2, SW15.3 (K)
unnamed: R20.2, SW20.3 (K)
unnamed: R21.2, SW21.3 (K)
unnamed: R22.2, SW22.3 (K)
unnamed: R23.2, SW23.3 (K)
unnamed: R24.2, SW24.3 (K)
unnamed: R25.2, SW25.3 (K)
unnamed: R30.2, SW30.3 (K)
unnamed: R31.2, SW31.3 (K)
unnamed: R32.2, SW32.3 (K)
unnamed: R33.2, SW33.3 (K)
unnamed: R34.2, SW34.3 (K)
unnamed: R35.2, SW35.3 (K)
unnamed: R40.2, SW40.3 (K)
unnamed: R41.2, SW41.3 (K)
unnamed: R42.2, SW42.3 (K)
unnamed: R43.2, SW43.3 (K)
unnamed: R44.2, SW44.3 (K)
unnamed: R45.2, SW45.3 (K)
unnamed: R50.2, SW50.3 (K)
unnamed: R51.2, SW51.3 (K)
unnamed: R52.2, SW52.3 (K)
unnamed: R53.2, SW53.3 (K)
unnamed: R54.2, SW54.3 (K)
unnamed: R55.2, SW55.3 (K)
unnamed: R60.2, SW60.3 (K)
unnamed: R61.2, SW61.3 (K)
unnamed: R62.2, SW62.3 (K)
VCC: SW0.4 (A), SW1.4 (A), SW2.4 (A), SW3.4 (A), SW4.4 (A), SW5.4 (A), SW10.4 (A), SW11.4 (A), SW12.4 (A), SW13.4 (A), SW14.4 (A), SW15.4 (A), SW20.4 (A), SW21.4 (A), SW22.4 (A), SW23.4 (A), SW24.4 (A), SW25.4 (A), SW30.4 (A), SW31.4 (A), SW32.4 (A), SW33.4 (A), SW34.4 (A), SW35.4 (A), SW40.4 (A), SW41.4 (A), SW42.4 (A), SW43.4 (A), SW44.4 (A), SW45.4 (A), SW50.4 (A), SW51.4 (A), SW52.4 (A), SW53.4 (A), SW54.4 (A), SW55.4 (A), SW60.4 (A), SW61.4 (A), SW62.4 (A), U1.21 (VCC)
col0: SW0.2, SW10.2, SW20.2, SW30.2, SW40.2, SW50.2, SW60.2, U1.7 (4/PD4)
col1: SW1.2, SW11.2, SW21.2, SW31.2, SW41.2, SW51.2, SW61.2, U1.8 (5/PC6)
col2: SW2.2, SW12.2, SW22.2, SW32.2, SW42.2, SW52.2, SW62.2, U1.9 (6/PD7)
col3: SW3.2, SW13.2, SW23.2, SW33.2, SW43.2, SW53.2, U1.10 (7/PE6)
col4: SW4.2, SW14.2, SW24.2, SW34.2, SW44.2, SW54.2, U1.11 (8/PB4)
col5: SW5.2, SW15.2, SW25.2, SW35.2, SW45.2, SW55.2, U1.12 (9/PB5)
ledOut: Q1.3 (D), R0.1, R1.1, R2.1, R3.1, R4.1, R5.1, R10.1, R11.1, R12.1, R13.1, R14.1, R15.1, R20.1, R21.1, R22.1, R23.1, R24.1, R25.1, R30.1, R31.1, R32.1, R33.1, R34.1, R35.1, R40.1, R41.1, R42.1, R43.1, R44.1, R45.1, R50.1, R51.1, R52.1, R53.1, R54.1, R55.1, R60.1, R61.1, R62.1
ledTrig: Q1.1 (G), R80.1, U1.13 (10/PB6)
row0: D0.1 (K), D1.1 (K), D2.1 (K), D3.1 (K), D4.1 (K), D5.1 (K), U1.20 (A3/PF4)
row1: D10.1 (K), D11.1 (K), D12.1 (K), D13.1 (K), D14.1 (K), D15.1 (K), U1.14 (16/PB2)
row2: D20.1 (K), D21.1 (K), D22.1 (K), D23.1 (K), D24.1 (K), D25.1 (K), U1.19 (A2/PF5)
row3: D30.1 (K), D31.1 (K), D32.1 (K), D33.1 (K), D34.1 (K), D35.1 (K), U1.15 (14/PB3)
row4: D40.1 (K), D41.1 (K), D42.1 (K), D43.1 (K), D44.1 (K), D45.1 (K), U1.18 (A1/PF6)
row5: D50.1 (K), D51.1 (K), D52.1 (K), D53.1 (K), D54.1 (K), D55.1 (K), U1.16 (15/PB1)
row6: D60.1 (K), D61.1 (K), D62.1 (K), U1.17 (A0/PF7)

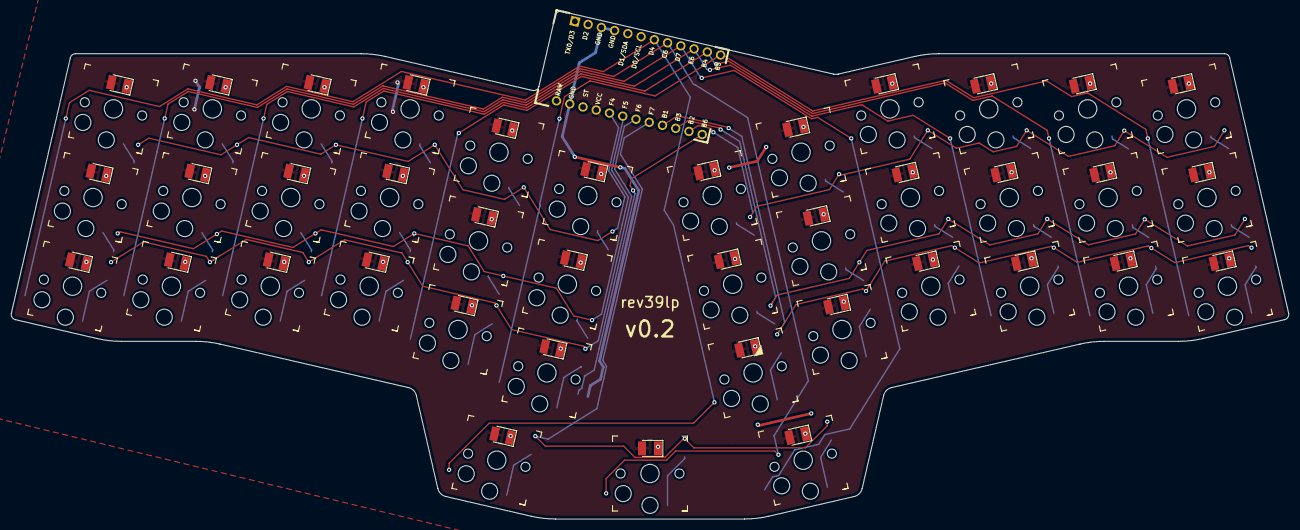
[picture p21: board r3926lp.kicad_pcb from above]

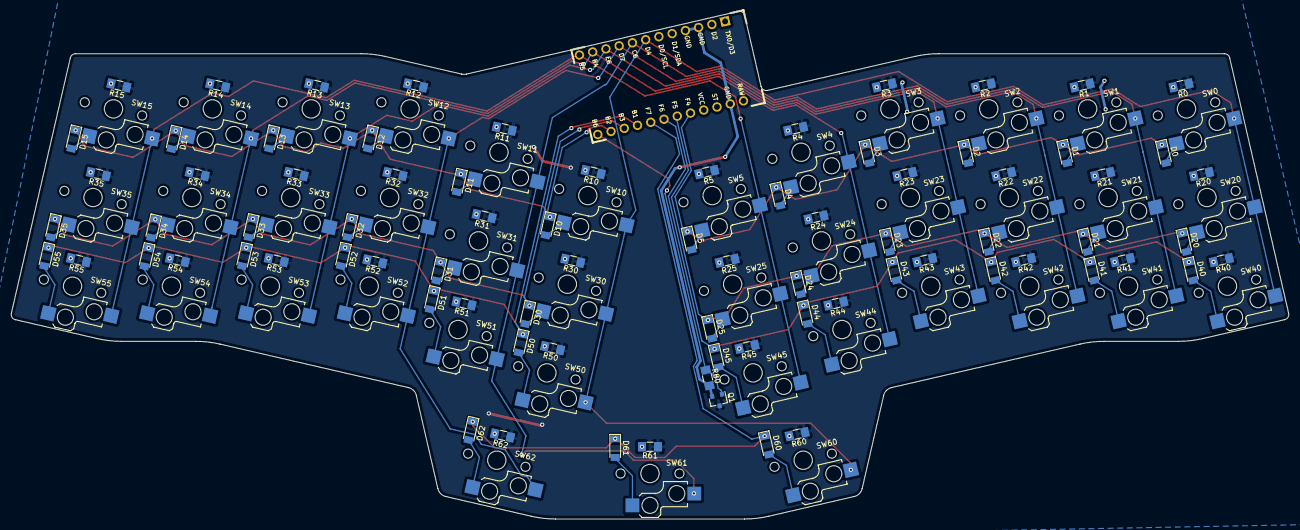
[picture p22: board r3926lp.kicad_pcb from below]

Board: 2 copper layers, 238.7 x 94.9 mm, 120 parts (81 on the bottom side), 95 nets.

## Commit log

2021-04-13 Initial B-sides release, r41lp_pcb
    [3Dâéâfâï_SKSNL.STEP, SKSLLA.STEP, SSSS811101.STEP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]
2021-04-23 README.md: Update BOM
2021-04-27 README.md: Update diode information
2021-04-27 Add schematic as pdf
2021-05-14 [device] 7teen: 17-position, pg1353
    [7teen.kicad_pcb, 7teen.sch]
2021-05-17 [keyboard] 7teen: schematic development
    [7teen.sch]
2021-05-17 [keyboard] 7teen: schematic & pcb development
    [7teen.sch]
2021-05-18 [keyboard] 7teen: pcb development
    [7teen.kicad_pcb, layout_7teen.dxf]
2021-06-11 [keyboard] 7teen:version update
    Application of lessons-learned
    [7teen.kicad_pcb, 7teen.sch]
2021-06-14 [kicad] Add single pg1353/1350 footprint
2021-06-14 [keyboard] 7teen: Minor pcb tweaks
    [7teen.kicad_pcb]
2021-06-24 Refactor projects & symbol/footprint libraries
    [41_1350_pcb.kicad_pcb, 41_1350_pcb.sch, 41_1350_switchPlate.kicad_pcb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]
2021-06-29 [keyboard] 7teen :: v0.2
    [7teen.kicad_pcb]
2021-06-29 [keyboard] reviung41_1353: Initial release
    [41_1353_switchplate.kicad_pcb, 41_1353_switchplate.sch, r41l2.kicad_pcb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]
2021-06-29 [keyboard] reviung39_1350: Initial release
    [r3926lp.kicad_pcb, r3926lp.sch, r39_switchPlate.kicad_pcb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]
2021-09-28 [kicad] Add combo footprint: pg1353_ec11rotSw
2021-09-28 [kicad] Footprint cleanup
2021-11-16 [kicad] migrate libraries to 5.99x
2021-11-16 [kicad] Add component: Holyiot-18010
2021-11-16 [kicad] Update combo footprint: pg1353_ec11rotSw
2021-11-16 [kicad] Update pg1353.kicad_mod
2021-11-16 [kicad] Add fuse_1206.step to 3d library
2021-11-16 [keyboard] Introduce one42
    Long Live Ahokore!
    [one42.dsn, one42.kicad_pcb, one42.kicad_sch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]
2021-11-16 [project] One42: Update schematic & PDF
    [one42.kicad_sch, one42_matrix.kicad_sch]
2021-11-16 One42: Promote to own directory
    [one42.dsn, one42.kicad_pcb, one42.kicad_sch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]
2021-11-18 [kicad] .gitignore additions
    * 'fp-info-cache' is regenerated each time Kicad is used, so does not need to be carried through the repo.
    * Ignore 'backup' directories throughout this repo
2021-11-18 [kicad] Move '3d-files' into relevant component library
    [3Dâéâfâï_SKSNL.STEP, SKSLLA.STEP, SSSS811101.STEP]
2021-11-23 [one42] Add skidPlate
    [skidPlate-B_Cu.gbl, skidPlate-B_Mask.gbs, skidPlate-B_Paste.gbp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]
2021-11-23 [one42] Add cover
    [cover-B_Cu.gbr, cover-B_Mask.gbr, cover-Edge_Cuts.gbr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]
2021-11-23 [one42] Add switchPlate
    [switchPlate-B_Cu.gbl, switchPlate-B_Mask.gbs, switchPlate-B_Paste.gbp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]
2021-11-23 [one42] relocate kicad-project-footprint lib
    [cover.kicad_pcb]
2021-11-29 [one42] Fabrication files: pcb v0.1
    [bom.xls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]
2021-12-09 [one42] Remove non-archived gerber files
    [cover-B_Cu.gbr, cover-B_Mask.gbr, cover-Edge_Cuts.gbr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]
